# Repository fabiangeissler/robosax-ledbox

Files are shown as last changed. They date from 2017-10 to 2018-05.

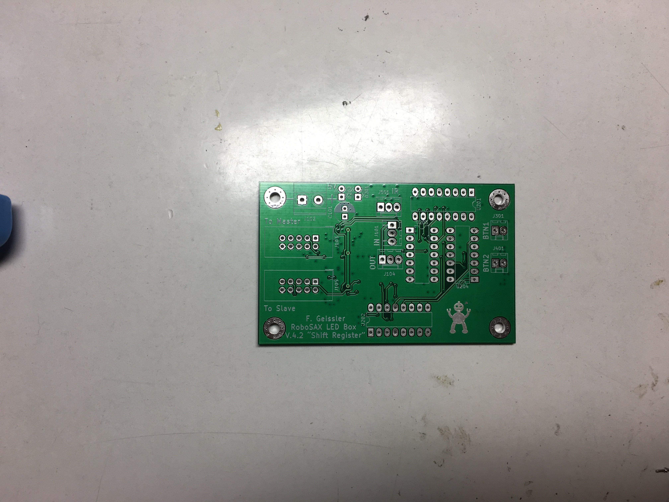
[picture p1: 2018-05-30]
Dokumentation/Fotos/IMG_1938.JPG

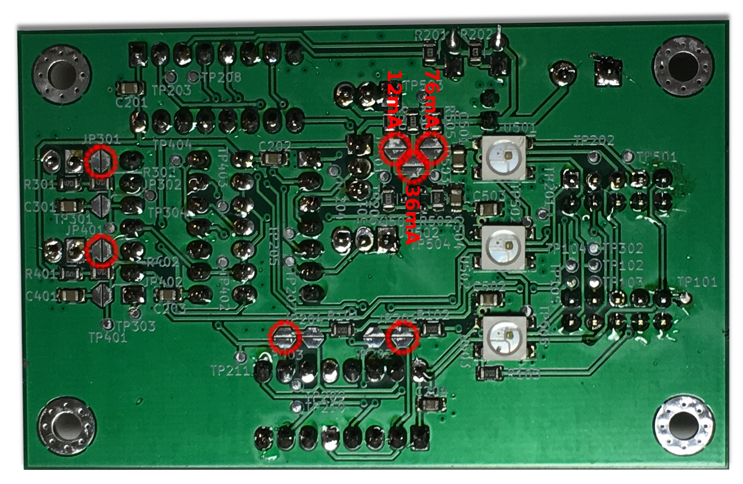
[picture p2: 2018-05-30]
Dokumentation/Fotos/bot_ass.png

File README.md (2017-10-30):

# robosax-ledbox
Bestandteil des Spielfeldes zum RoboSAX Wettbewerb 2018.  

Die Boxen bestehen aus einer RGB LED zur Statusanzeige und einem Button zur Aktivierung durch die Roboter. Zusätzlich enthält jede Box eine infrarot LED in der Nähe des Buttons um Daten an den Roboter zu übermitteln. Die Nutzung der IR LED ist für den Wettbewerbsablauf nicht notwendig, kann aber Vorteile bringen.  

Genauere Informationen zum mechanichen Aufbau, Maße und Datenprotokolle folgen sobald sie festgelegt wurden.

Fabian Geißler  
RoboSAX Team

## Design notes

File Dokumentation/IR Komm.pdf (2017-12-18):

# RoboSAX 2018

## - Bereich Spielfeldbau -

## Information: Infrarotkommunikation der Spielfeldelemente

## UNVOLLSTÄNDIGE ARBEITSFASSUNG

Einführung

Die optisch-mechanischen Spielfeldelemente (Taster mit LED Anzeige) werden erstmals zum RoboSAX 2018 eingesetzt. Die 24 Einheiten pro Spielfeld sind untereinander vernetzt, wodurch einerseits ein Spielmodus über beide Spielfeldhälften, sowie eine automatische Echtzeitauswertung und Zeitmessung möglich wird.
Darüberhinaus besitzt jede Einheit eine infrarot Schnittstelle, über die der Roboter den aktuellen Spielfeldstatus auslesen kann. Die exakten Spezifikationen dieser Schnittstelle werden in diesem Dokument erläutert.

Ablauf

Nachdem der Taster eines Spielfeltelements betätigt wurde wird die Infrarotschnittstelle aktiviert. Diese verwendet das UART Protokoll zum senden der Daten. Der Empfang von Daten bzw. das Senden von Daten an die Elemente ist nicht möglich.
Zunächst wird ein Byte mit dem Wert 0xAA gesendet. Das entspricht einem umschalten des Datensignals bei jedem Bit und kann zum aufsynchronisieren verwendet werden. Danach folgen drei Bytes, also insgesamt 24 bit, welche eine Information über den Status der jeweiligen Station geben. Bits 0 bis 11 entsprechen Spielfeldhälfte A und Bits 12 bis 23 entsprechen Spielfeldhälfte B.
Eine erneute Kommunikation wird erst durch erneutes drücken des Buttons aktiviert.

Mechanische Daten

- folgt -

Opto-Elektrische Eigenschaften

Elektrische Eigenschaften (interner 8MHz Osc. unkallibriert)

Parameter | Symbol | Min | Typ | Max | Einheit
Spitzenwert Wellenlänge | λp | | 940 | | nm
Spektrale Bandbreite | Δλ | | 45 | | nm
Strahlungsintensität | IE | | 35 | | mW/sr
Abstrahlwinkel | θ | | 35 | | °
Parameter | Symbol | Min | Typ | Max | Einheit
Modulationsfrequenz | fmod | 34,6 | 38 | 38,5 | kHz
Baudrate | Rbaud | 365 | 400 | 405 | 1/s

Protokoll

Da bei UART der normale Zustand einem HIGH Pegel auf der Leitung entspricht wird dieser bei der Infrarotkommunikation durch die Abwesenheit des modulierten Signals repräsentiert. Ein LOW Pegel wird entsprechend durch das modulierte Signal angezeigt.
Die Übertragung eines Byte sieht wie folgt aus:

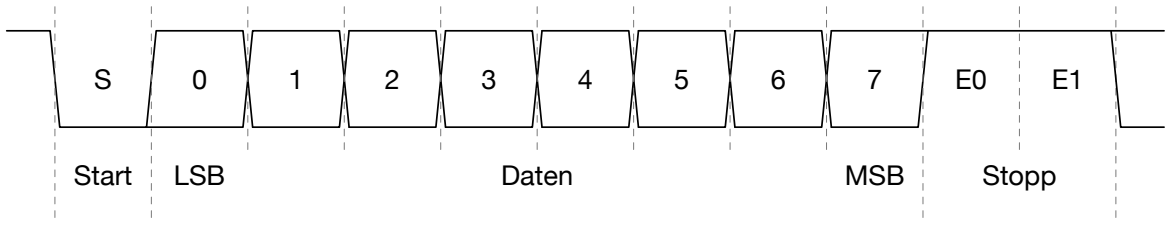
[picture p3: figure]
Start; LSB; Daten; MSB; Stopp

Das modulierte Signal kann mithilfe eines infrarot Demodulationsempfängers, wie zum Beispiel dem TSOP4438 in ein elektrisches TTL UART Signal gewandelt werden. Im Folgenden ist beispielhaft die Übertragung des Bytes 0xAA dargestellt. Der rote Graph stellt dabei das infrarot Signal dar, während der Schwarze den entsprechenden Ausgang des Demodulators zeigt.
Da der Ausgang des Empfängers (hier TSOP4438) bereits das Signal invertiert kann es direkt

auf die UART Peripherie eines Mikrocontrollers gegeben und wie normale UART Daten ausgelesen werden.

Start | MSB | Daten (0xAA) | LSB | Stopp
0 | 1 | 0 | 1 | 0 | 1 | 0 | 1 | 0 | 1 | 1

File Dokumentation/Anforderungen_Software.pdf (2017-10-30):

### Programm allgemein

- Aufgaben:
- System Timer mit Timer1 (16 bit) -> 1us bis 1ms Systemtakt für Buszugriff, Debounce,

Systemzeit und Timings mit geringer Priorität
(muss man testen, wie tief man mit der Zeit gehen kann)
- PWM Steuerung der RGB LED -> Hybrid PWM (Timer 0 Interrupts + Software)
- Button Auswertung und Debouncing, ohne Interrupt.
- INT0 (Button) und INT1 (Bus) nur zum wecken aus IDLE verwenden.
- Buszugriff mit System Timer und UART
- IR LED Datenübertragung Timing mit System Timer
- Adressierung
- Jeder Controller bekommt den seine laufende Nummer (oder einen Hash davon, oder eine

eindeutige Zufallszahl) in den EEPROM geschrieben. Dieser Wert dient zur Adressierung des Controllers auf dem Bus.
- Um der Steuereinheit die Adressen und Positionen bekannt zu machen muss eine Setup

Prozedur entwickelt werden. Z.B. kann von der Steuereinheit ein Setup Modus ausgerufen (Broadcast) werden. In diesem sendet jede LED Box bei Tastendruck ihre eigene Adresse an die Steuereinheit. Um die Positionen zuzuordnen verlangt die Setup Prozedur eine feste Reihenfolge in der die Taster gedrückt werden müssen (z.B. A1 bis A12 und dann B1 bis B12).
- Zufall
- Die Adresse dient zusätzlich als erster seed für den Zufallsgenerator, damit von Anfang an

verschiedene Zufallszahlen garantiert werden können
- Bei jedem Tastendruck wird die aktuelle Systemzeit, evtl. verrechnet mit der Adresse, als neuer seed verwendet.

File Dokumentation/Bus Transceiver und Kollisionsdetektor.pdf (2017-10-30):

### Bus Transceiver

- bisher: SN75176B (Datenblatt) (http://www.ti.com/lit/ds/symlink/sn75176a.pdf)
- veraltet
- hoher Stromverbrauch: 35mA - 50mA
- neu: ST485C (Datenblatt) (http://www.st.com/content/ccc/resource/technical/document/datasheet/4b/81/a8/cd/8a/72/47/82/CD00002183.pdf/files/CD00002183.pdf/jcr:content/translations/en.CD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) oder alternativ ADM485 (Datenblatt) (http://www.analog.com/media/en/technical-documentation/data-sheets/ADM485.pdf)
- 300µA Stromverbrauch (+ Ausgangsströme)
- max. 64 Transceiver pro Bus
- max. 2.5Mbps
- max. Anstiegs/Abfallzeit des Senders: 40ns (relevant für Kollisionsdetektor)
- Bei Kollision am Ausgang: Überlagerung von Fig. 12 und Fig. 13 auf S. 12 im Datenblatt

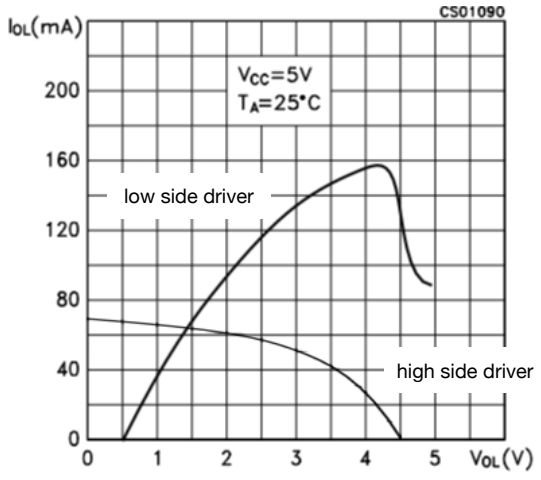
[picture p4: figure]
high side driver; low side driver
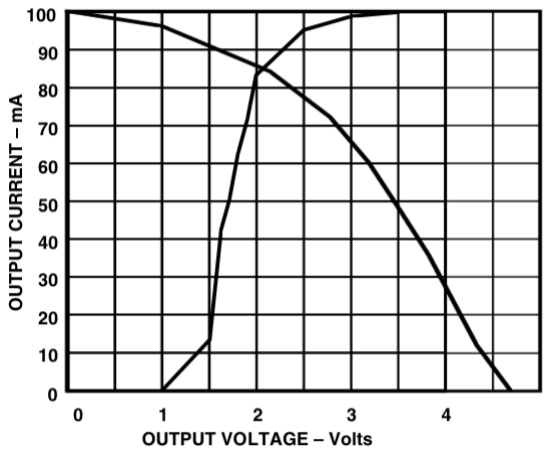
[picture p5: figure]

- es wird sich eine Spannung um 1,5V bei ca. 60mA einstellen
- Bei einer Leitungslänge von 10m mit 216Ω/km (Datenblatt), (http://cdn-reichelt.de/documents/datenblatt/C600/FLACHBANDKABEL.pdf) also 2,16Ω Leitungswiderstand

ergibt sich ein Spannungsabfall im Kabel von rund 130mV. Da dieser Wert über der Hysterese des Empfängers liegt würde der Empfänger auch im Falle einer Kollision genau das empfangen, was der zugehörige Sender sendet. Eine Kollisionserkennung ist so also genau wie beim SN75176B nicht möglich.
- Die Kollisionsdetektorschaltung wird auch hier benötigt, diesmal aber zur Erkennung des

Abfalls des high Pegels.

Sender Ausgangsstrom über Ausgangsspannung ST485C (links) und ADM485 (rechts)

- Kollisionsdetektor

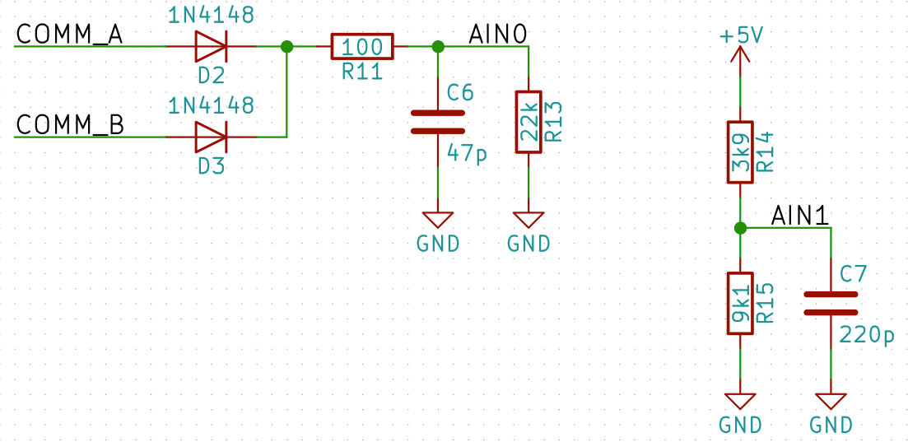
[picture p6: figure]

- Mit den Dioden D2 und D3 wird immer der high Pegel abgegriffen, unabhängig davon, ob er gerade auf A oder B vorherrscht. Der Tiefpass R11 und C6 dient zum Eliminieren der Umschalteinbrüche. R13 erzwingt einen Stromfluss durch die Dioden.
- Bei Betrachtung des letzten Busteilnehmers sieht der Sender standardmäßig als Last die

Leitungsimpedanz und den parallelgeschalteten Abschlusswiderstand. Wenn beide rund 150Ω betragen, ergibt sich eine Last von 75Ω. Im Diagramm unten ergibt das ungefähr den in rot markierten Arbeitspunkt mit einer Differenzspannung von rund 2,7V und 36mA.

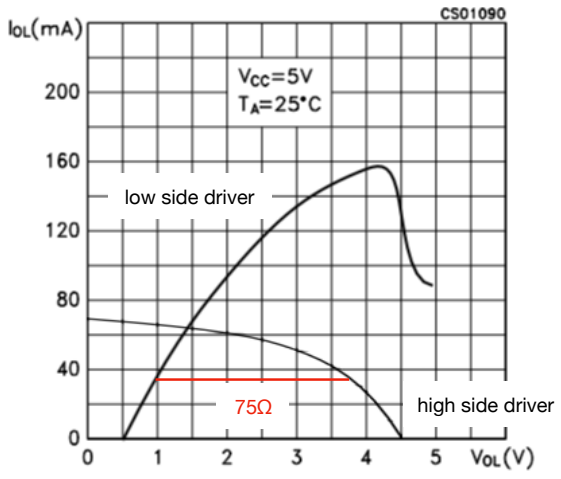
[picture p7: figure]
high side driver; low side driver

- Der Kollisionsdetektor darf also erst bei einem Abfall des high Pegels unter ca. 3,5V oder besser, unter Beachtung von Toleranzen, unter 3V anschlagen.
- Unter Beachtung der Diodenspannung mit 0,5V bis 0,7V darf die Spannung an AIN also nicht unter 2,4V fallen. Da AIN0 und AIN1 im Analog Comparator des Mikrocontrollers verglichen werden muss AIN1 auf diese 2,4V eingestellt werden. Unter Zuhilfenahme des Voltage Divider Calculator von TI (http://www.ti.com/download/kbase/volt/volt_div3.htm) ergeben sich dafür günstige Werte von R14 = 3,3kΩ und R15 = 2,2kΩ.

Sender Ausgangsstrom über Ausgangsspannung

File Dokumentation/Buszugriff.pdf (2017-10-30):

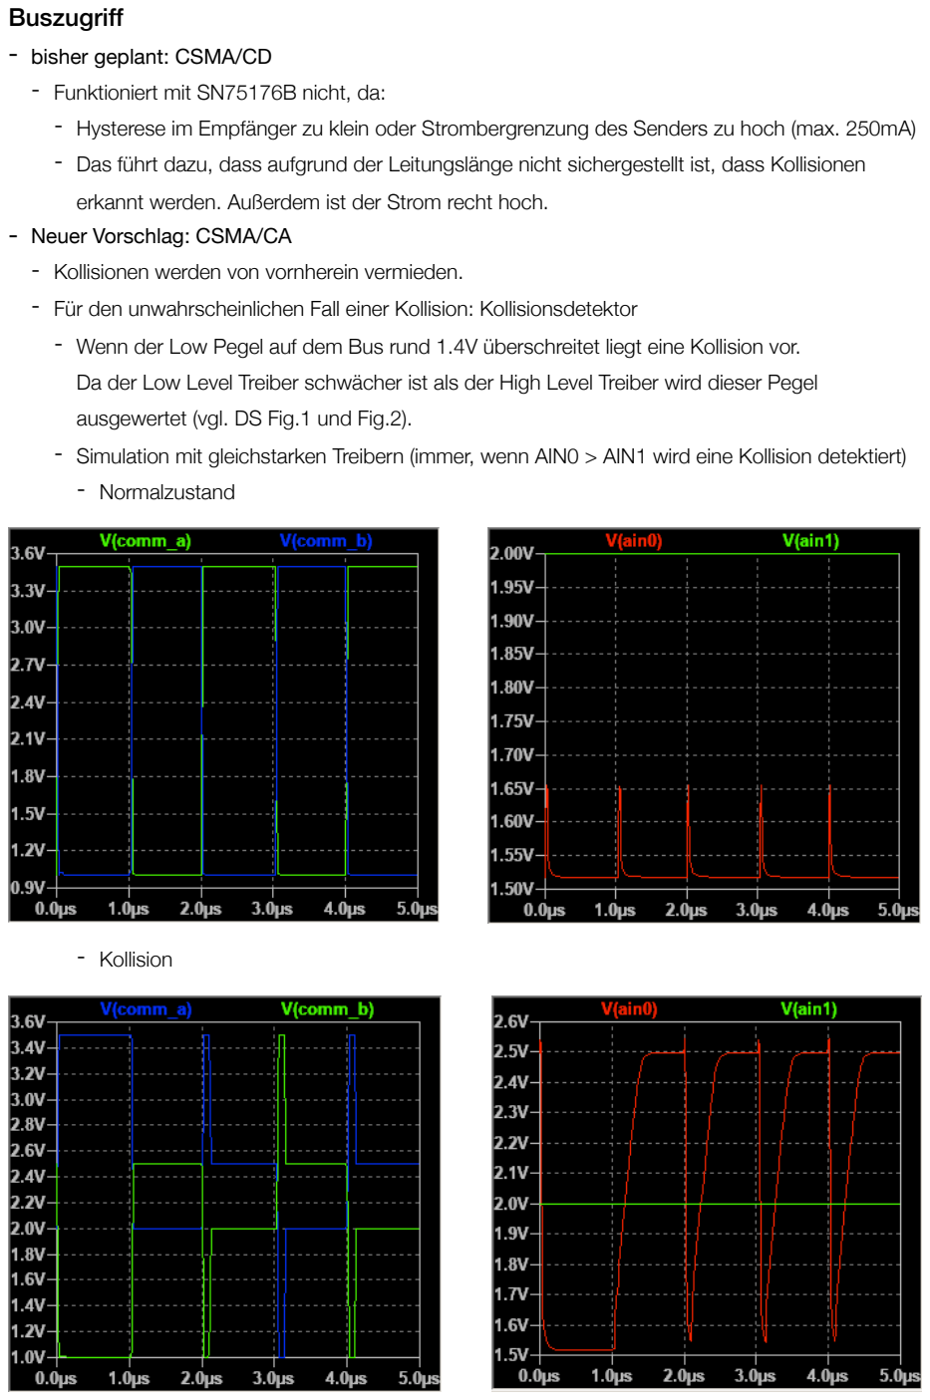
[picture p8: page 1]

### Buszugriff

- bisher geplant: CSMA/CD
- Funktioniert mit SN75176B nicht, da:
- Hysterese im Empfänger zu klein oder Strombergrenzung des Senders zu hoch (max. 250mA)
- Das führt dazu, dass aufgrund der Leitungslänge nicht sichergestellt ist, dass Kollisionen

erkannt werden. Außerdem ist der Strom recht hoch.
- Neuer Vorschlag: CSMA/CA
- Kollisionen werden von vornherein vermieden.
- Für den unwahrscheinlichen Fall einer Kollision: Kollisionsdetektor
- Wenn der Low Pegel auf dem Bus rund 1.4V überschreitet liegt eine Kollision vor.
Da der Low Level Treiber schwächer ist als der High Level Treiber wird dieser Pegel ausgewertet (vgl. DS Fig.1 und Fig.2).
- Simulation mit gleichstarken Treibern (immer, wenn AIN0 > AIN1 wird eine Kollision detektiert)
- Normalzustand
- Kollision

- Ablauf:
1. Teilnehmer wird eingeschaltet
2. Teilnehmer wartet für mindestens die CA (Collision Avoidance) Periode oder die Sendedauer eines Bytes (welche länger ist) und beobachtet den Bus
3. Wenn der Bus frei ist (RX = High Pegel) kann der Teilnehmer senden.
Dazu wird der Bus auf Low Pegel gezogen, es beginnt die CA Periode.
4. Nach einer zufälligen Zeit in der CA Periode wird der Bus freigegeben (Sender auf tristate)
5. Wenn der Bus auf Low bleibt kann nicht gesendet werden, da ein anderer Teilnehmer senden will und zufällig die längere Zeit „gewürfelt“ hat. Weiter mit 8.
6. Wenn der Bus auf High springt kann nach einem kurzen Delay (alle Teilnehmer müssen nach der Low-High Flanke aufwachen) angefangen werden zu senden.
Hierfür wird die UART Peripherie benutzt. Zuerst wird die Adresse des Empfängers gesendet. Danach können alle nicht angesprochenen Teilnehmer wieder schlafen.
7. Sollten zwei Teilnehmer gleichzeitig angefangen haben und auch die gleiche Zeit gezogen haben wird jetzt die Kollisionserkennung anschlagen. In diesem Fall muss von dem Teilnehmer, der sendet und die Kollision erkannt hat, die Kollisionserkennung der anderen Sender provoziert werden. Dafür wird der Bus für die Sendedauer eines Bytes Low gehalten.
8. Wenn der Bus länger als die Sendedauer eines Bytes High bleibt ist er wieder frei. Zurück zu 3.
- warum nicht Daisychain?
- Für Daisychain würde ein weiterer Kommunikationsport am Mikrocontroller und ein weiterer Transceiver benötigt. KO Kriterium ist hier der nicht verfügbare weitere Kommunikationsport.
- Außerdem müsste jedes mal die Nachricht über alle Zwischenstationen gereicht werden. Bei

Fehler einer Station kann ein ganzer Bereich nicht mehr angesprochen werden.

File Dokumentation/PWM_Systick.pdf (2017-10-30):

### Erweiterung der PWM Auflösung

- Problem:
- Der ausgewählte Controller hat nur zwei 16 Bit hardware PWM Kanäle, die restlichen vier

hardware PWM Kanäle haben nur eine Auflösung von 8 Bit.
- Für die RGB LED werden drei Kanäle benötigt.
- Aufgrund der nichtlinearen Helligkeitsempfindlichkeit des Auges wird im kleinen Helligkeitsbereich

eine höhere Auflösung der PWM von mindestens 12 Bit gefordert.
- Lösung 1: Dithering (pwm_dither.h)
- Mithilfe von Dithering kann durch eine vergrößerte Zeitauflösung auch die Auflösung der Helligkeitsstufen vergrößert werden. Dabei hilft die Trägheit des Auges, auf welcher das gesamte Dimmprinzip per PWM basiert.
- Anstatt einer PWM mit z.B. 200Hz wird jetzt eine PWM mit 400Hz genutzt. Dabei wird immer in einer Periode das nächst mögliche geringere Tastverhältnis als der gesetzte Wert verwendet. In der nächsten Periode wird das nächsthöhere Tastverhältnis gesetzt. Im Mittel ergibt sich also genau die Helligkeit wischen beiden Tastverhältnissen. Die PWM Auflösung wurde so um ein Bit erweitert. Die Auflösung kann also mit jeder Frequenzverdopplung um ein Bit erhöht werden.
- Bei 12 Bit wird also eine Frequenz von 200Hz * 2^4 = 3,2kHz benötigt
- Vorteile:
- Benötigte bittiefe kann dynamisch an den eingestellten Tastgrad angepasst werden, wodurch

auch die Frequenz an den jeweiligen Tastgrad angepasst wird und die benötigten CPU Zyklen geringer werden.
- Nachteile:
- Hohe PWM Frequenz stellt hohe Anforderungen an die Flankensteilheit des LED Treibers, sonst wird die Helligkeit insgesamt abgesenkt. Bei geringer Flankensteilheit gibt es zusätzlich Helligkeitssprünge beim Umschalten zwischen verschiedenen Frequenzen.
- Lösung 2: Hybrid zwischen Hardware und Software PWM (pwm_hybrid.h)
- Die vorhandene 8 Bit PWM wird durch einen weiteren 8 Bit Softwarezähler erweitert, welcher

immer beim Überlauf des Hardwarezählers hochgezählt wird. Dadurch verhält er sich exakt wie ein 16 Bit Hardware Kanal, benötigt aber Zusätzliche CPU Zyklen alle 256 Takte.
- Beim Einstellen des Tastverhältnisses wird geprüft, bei welchem Zählerstand des Softwarezählers

der Ausgang von Low auf High springen muss (software compare, SC) und bei welchem Stand des Hardwarezählers dieser Sprung stattfindet (hardware compare, HC).
In jedem Überlauf des Hardwarezählers werden die Werte für die nächste Periode (nicht die direkt folgende) gesetzt. Hier wird nun unterschieden, liegt der Softwarezähler unter SC, wird der Hardware Tastgrad auf 0xFF (Low Pegel) gesetzt. Liegt er über SC wird der Tastgrad auf null (High Pegel) gesetzt. Wenn er gleich SC ist, wird der Hardware Tastgrad auf HC gesetzt. Dadurch wird das Umschalten im korrekten Moment von der Hardware übernommen.

- Vorteile:
- PWM Frequenz wird gering gehalten
- Verhält sich exakt wie ein 16 Bit Hardware Timer
- Nachteile
- Im mittel höhere CPU Last als Dithering, rund 77 Zyklen alle 256 Zyklen (rund 30% Grundlast). Dieser Wert verringert sich allerdings mit der PWM Frequenz bzw. dem Prescaler.
- Lösung 2 ist die Empfohlene

### Systick

- Systick wird vom 16 Bit Timer gesteuert und ist damit abhängig von dessen Auflösung.
- Bei einer Auflösung von 14 Bit bei 16MHz entspricht ein Tick 1,024ms

Die Interruptroutine benötigt 56 Zyklen alle 16385 Takte (0,34% Last)

### Mögliche Änderungen

- In der aktuellen Ausführung haben die PWMs alle eine Auflösung von 14 Bit und einen Prescaler von eins, wodurch sich oben genannter Systick und eine PWM Frequenz von 977Hz (bei 16MHz) ergibt.
- Mit einem Prescaler von acht und mit 12 Bit Auflösung würde die PWM Frequenz auf 488Hz (bei 16MHz) verringert werden. Der Systick würde sich entsprechend verdoppeln. Die CPU Auslastung durch die Hybrid PWM verringert sich allerdings um Faktor acht mit 77 Zyklen alle 2048 Takte (3,8% Grundlast).
- Der Systick könnte zusätzlich im Überlauf des 8 Bit Timers berechnet werden. Dadurch würde ich die Genauigkeit des Systick erheblich verbessern, aber die CPU Auslastung ansteigen. Konkret ergäbe sich bei einem Prescaler von 1 ein Systick alle 16µs und eine Auslastung von zusätzlichen 20 Zyklen pro Überlauf des Timers, also 97 Zyklen alle 256 Takte bzw. 38%.
Mit einem Prescaler von 8 ergäbe sich ein Systick alle 128µs und eine Auslastung von 97 Zyklen alle 2048 Takte bzw. 4,7%.
Für diesen zweiten Fall wäre die Änderung zu empfehlen, damit die Genauigkeit des Systick, gerade für die Kommunikation nicht zu gering wird.

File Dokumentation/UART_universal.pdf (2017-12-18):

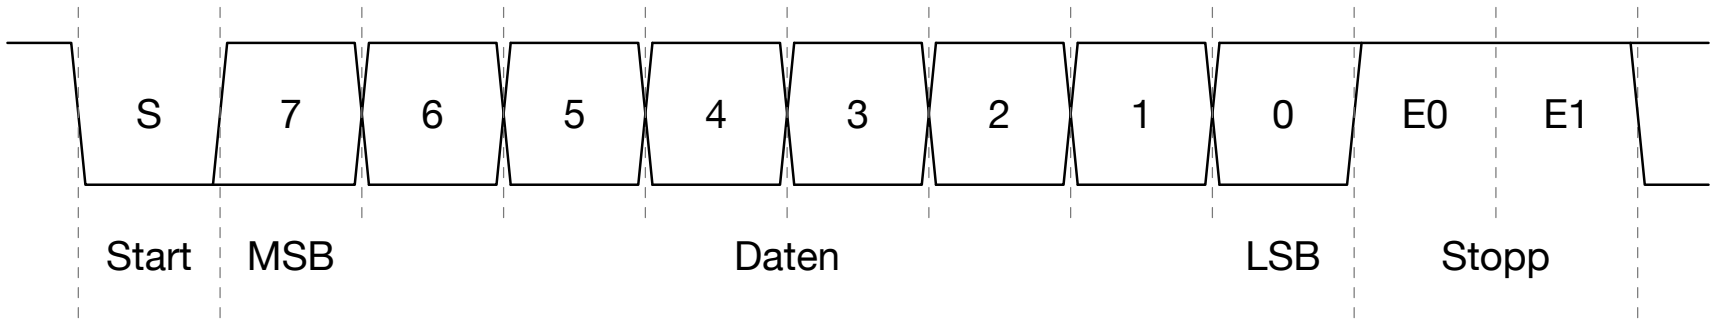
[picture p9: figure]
Start; MSB; Daten; LSB; Stopp

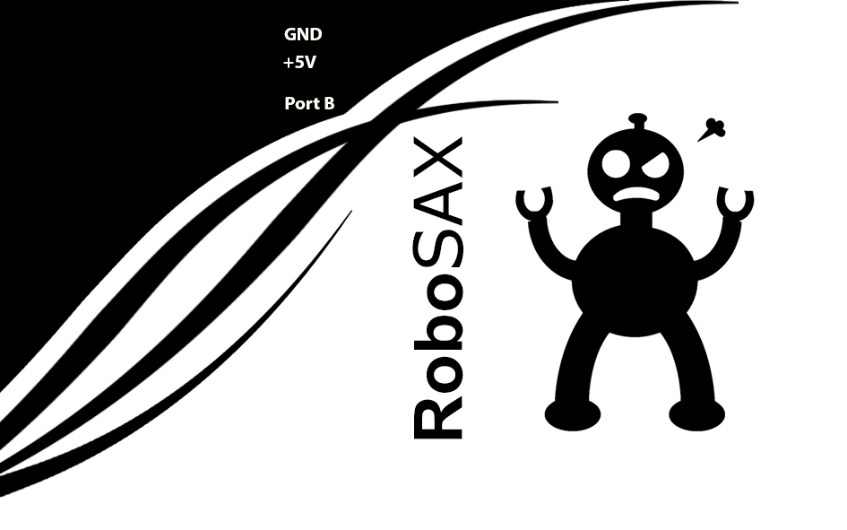
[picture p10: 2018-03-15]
KiCad/SC images/board Kopie.png

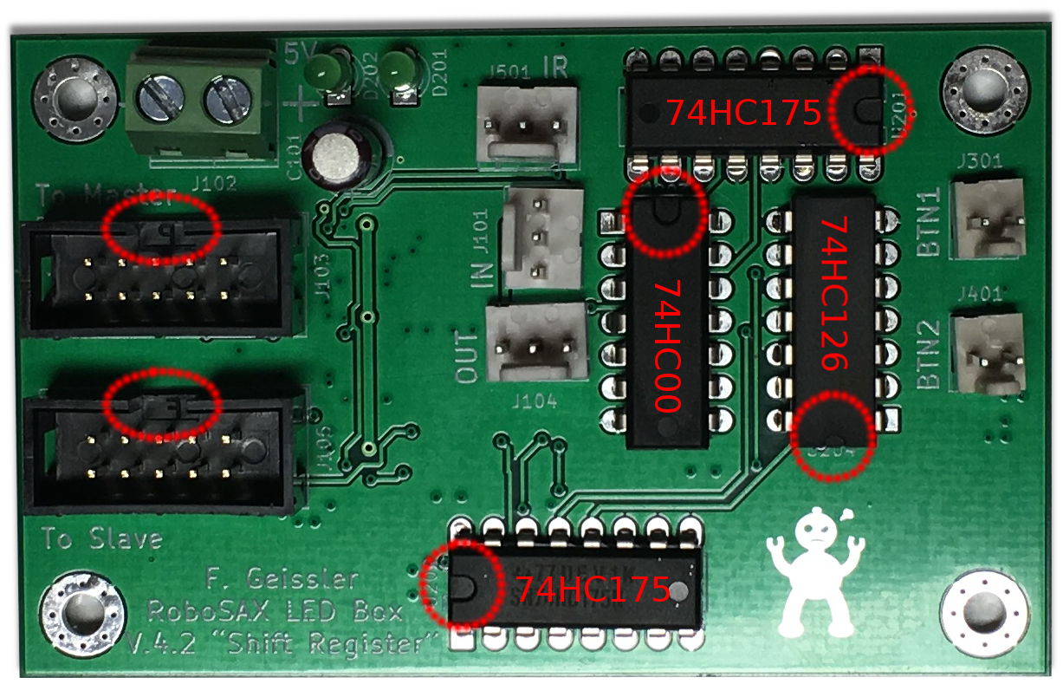
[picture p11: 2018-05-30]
Dokumentation/Fotos/top_ass.png

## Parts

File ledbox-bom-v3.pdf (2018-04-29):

### Table 1

Item | Qty | Reference(s) | Value | LibPart | Footprint | | Alternative | Assembly | Elecrow ID | Elecrow Part | Elecrow Value | Part ID | Digikey | Mouser | Comment
1 | 4 | C201; C501; C502; C503 | 10u | device:C | Capacitors_SMD:C_0805 | 0805 | | | 16532 | C15850 | 10uF (106) ±10% 25V
2 | 3 | C202; C306; C307 | 22p | device:C | Capacitors_SMD:C_0805 | 0805 | | | 2156 | C1804 | 22pF (220) ±5% 50V
3 | 1 | C203 | 470p | device:C | Capacitors_SMD:C_0805 | 0805 | | | 2095 | C1743 | 470pF (471) ±10% 50V
4 | 8 | C301; C302; C303; C304; C305; C402; C403; C504 | 100n | device:C | Capacitors_SMD:C_0805 | 0805 | | | 50686 | C49678 | 100nF(104) ±10% 50V
5 | 1 | C401 | 4u7 25V | device:CP | Capacitors_THT:CP_Radial_D5.0mm_P2.00mm | P2.00mm | | DNP
6 | 1 | C404 | 47u 16V | device:CP | Capacitors_THT:CP_Radial_D6.3mm_P2.50mm | P2.50mm | | | | | | 47µF 16V aluminum electrolytic capacitor | https://www.digikey.de/product-detail/de/panasonic-electronic-components/ECA-1CM470I/P19515CT-ND/6109413 | https://www.mouser.de/ProductDetail/Panasonic/ECA-1CM470I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 | Or similar part
7 | 1 | CON301 | AVR_ISP | atmel:AVR-ISP-6 | Connectors_IDC:IDC-Header_2x03_Pitch2.54mm_Straight | Straight | | | | | | IDC-Header 02x03 Pitch 2.54mm Straight | https://www.digikey.de/product-detail/de/amphenol-fci/75869-331LF/609-5122-ND/1523699 | https://www.mouser.de/ProductDetail/Wurth-Electronics/61200621621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 | Or similar part
8 | 3 | D201; D202; D401 | 1N4148 | device:D | Diodes_SMD:D_SOD-123 | SOD-123 | | | | | | 1N4148W-7-F | https://www.digikey.de/product-detail/de/diodes-incorporated/1N4148W-7-F/1N4148W-FDICT-ND/815280 | https://eu.mouser.com/ProductDetail/Diodes-Incorporated/1N4148W-7-F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
9 | 2 | D402; D502 | LED2 | device:LED | LEDs:LED_D3.0mm | D3.0mm | | DNP
10 | 1 | D403 | PMEG4010ER | device:D_Schottky | Diodes_SMD:D_SOD-123 | SOD-123 | MBR140ESFT3G | | | | | PMEG4010ER,115 | https://www.digikey.de/product-detail/de/nexperia-usa-inc/PMEG4010ER115/1727-5213-1-ND/2531812 | https://www.mouser.de/ProductDetail/Nexperia/PMEG4010ER115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
11 | 1 | D501 | LED1 | device:LED | LEDs:LED_D3.0mm | D3.0mm | | DNP
12 | 1 | J201 | Bus | Connector:Conn_02x05_Odd_Even | Connectors_IDC:IDC-Header_2x05_Pitch2.54mm_Straight | Straight | | | | | | IDC-Header 02x05 Pitch 2.54mm Straight | https://www.digikey.de/product-detail/de/on-shore-technology-inc/302-S101/ED1543-ND/2178422 | https://www.mouser.de/ProductDetail/Wurth-Electronics/61201021621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 | Or similar part
13 | 1 | J301 | Power B | Connector:Conn_02x06_Odd_Even | Socket_Strips:Socket_Strip_Straight_2x06_Pitch2.54mm | Pitch2.54mm | | DNP
14 | 1 | J302 | Port B | Connector:Conn_01x06 | Socket_Strips:Socket_Strip_Straight_1x06_Pitch2.54mm | Pitch2.54mm | | DNP
15 | 1 | J303 | Spare | Connector:Conn_01x02 | Socket_Strips:Socket_Strip_Straight_1x02_Pitch2.54mm | Pitch2.54mm | | DNP
16 | 1 | J304 | UART | Connector:Conn_01x03 | Socket_Strips:Socket_Strip_Straight_1x03_Pitch2.54mm | Pitch2.54mm | | DNP
17 | 1 | J305 | ADC6 | Connector:Conn_01x03 | Socket_Strips:Socket_Strip_Straight_1x03_Pitch2.54mm | Pitch2.54mm | | DNP
18 | 1 | J306 | ADC7 | Connector:Conn_01x03 | Socket_Strips:Socket_Strip_Straight_1x03_Pitch2.54mm | Pitch2.54mm | | DNP
19 | 1 | J401 | 6.5V-12V | Connector:Conn_01x02 | TerminalBlock_MetzConnect:TerminalBlock_MetzConnect_Type055_RT01502HDWU_Pitch5.00mm | Pitch5.00mm | | DNP
20 | 1 | J402 | 5V | Connector:Conn_01x02 | TerminalBlock_MetzConnect:TerminalBlock_MetzConnect_Type055_RT01502HDWU_Pitch5.00mm | Pitch5.00mm | | | | | | Terminal 2 Pin Pitch 5mm | https://www.digikey.de/product-detail/de/amphenol-anytek/VI0201550000G/609-3927-ND/2261273 | https://www.mouser.de/ProductDetail/Bussmann-Eaton/EM367502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 | Or similar part
21 | 1 | J501 | IR LED | Connector:Conn_01x03 | Connectors_Molex:Molex_KK-6410-03_03x2.54mm_Straight | Straight | | | | | | Molex locking header Pitch 2.54mm 3 Pin | https://www.digikey.de/product-detail/de/sullins-connector-solutions/SWR25X-NRTC-S03-ST-BA/S9411-ND/2769653 | https://www.mouser.de/ProductDetail/Molex/22-28-0030?qs=sGAEpiMZZMs%252bGHln7q6pmxD%2f5kNJnZVeZCYy0rFr0qA%3d | Or similar part
22 | 1 | J502 | Button | Connector:Conn_01x02 | Connectors_Molex:Molex_KK-6410-02_02x2.54mm_Straight | Straight | | | | | | Molex locking header Pitch 2.54mm 2 Pin | https://www.digikey.de/product-detail/de/sullins-connector-solutions/SWR25X-NRTC-S02-ST-BA/S9407-ND/2769652 | https://www.mouser.de/ProductDetail/Molex/22-28-0020?qs=sGAEpiMZZMs%252bGHln7q6pm%252bS0pk2Wo0XxW6Wmp6I5P6k%3d | Or similar part
23 | 1 | Q501 | NTR4003N | device:Q_NMOS_GSD | TO_SOT_Packages_SMD:SOT-23 | SMD:SOT-23 | Logic Level N-ch 500mA MOS | | | | | NTR4003NT1G | https://www.digikey.de/product-detail/de/on-semiconductor/NTR4003NT1G/NTR4003NT1GOSCT-ND/1967270 | https://www.mouser.de/ProductDetail/ON-Semiconductor/NTR4003NT1G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
24 | 5 | R201; R506; R507; R508; R509 | 10k | device:R | Resistors_SMD:R_0805 | 0805 | | | 18102 | C17414 | 10KΩ (1002) ±1%
25 | 5 | R202; R204; R301; R302; R303 | 1k | device:R | Resistors_SMD:R_0805 | 0805 | | | 18201 | C17513 | 1KΩ (1001) ±1%
26 | 1 | R203 | 150Ω | device:R | Resistors_SMD:R_0805 | 0805 | | | 18159 | C17471 | 150Ω (1500) ±1%
27 | 3 | R205; R501; R504 | 100Ω | device:R | Resistors_SMD:R_0805 | 0805 | | | 18096 | C17408 | 100Ω (1000) ±1%
28 | 1 | R206 | 22k | device:R | Resistors_SMD:R_0805 | 0805 | | | 18248 | C17560 | 22KΩ (2202) ±1%
29 | 1 | R207 | 3.3k | device:R | Resistors_SMD:R_0805 | 0805 | | | 26753 | C26010 | 3.3KΩ (3301) ±1%
30 | 2 | R208; R401 | 2.2k | device:R | Resistors_SMD:R_0805 | 0805 | | | 18208 | C17520 | 2.2KΩ (2201) ±1%
31 | 1 | R502 | 100k | device:R | Resistors_SMD:R_0805 | 0805 | | | 18095 | C17407 | 100KΩ (1003) ±1%
32 | 1 | R503 | 220Ω | device:R | Resistors_SMD:R_0805 | 0805 | | | 18245 | C17557 | 220Ω (2200) ±1%
33 | 1 | R505 | 47Ω | device:R | Resistors_SMD:R_0805 | 0805 | | | 18402 | C17714 | 47Ω (47R0) ±1%
34 | 2 | R510; R511 | 470Ω | device:R | Resistors_SMD:R_0805 | 0805 | | | 18398 | C17710 | 470Ω (4700) ±1%
35 | 1 | SW501 | Reset | Switch:SW_Push | Buttons_Switches_THT:SW_PUSH_6mm_h5mm | h5mm | | DNP
36 | 1 | SW502 | Push 1 | Switch:SW_Push | Buttons_Switches_THT:SW_PUSH_6mm_h5mm | h5mm | | DNP
37 | 1 | SW503 | Push 2 | Switch:SW_Push | Buttons_Switches_THT:SW_PUSH_6mm_h5mm | h5mm | | DNP
38 | 1 | U201 | ST485C | ledbox-newsymbols:SN75176B | Housings_SOIC:SOIC-8_3.9x4.9mm_Pitch1.27mm | Pitch1.27mm | | | | | | ST485CDR | https://www.digikey.de/product-detail/de/stmicroelectronics/ST485CDR/497-3734-1-ND/686452 | https://www.mouser.de/ProductDetail/STMicroelectronics/ST485CDR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
39 | 1 | U301 | ATMEGA88A-AU | atmel:ATMEGA88A-AU | Housings_QFP:TQFP-32_7x7mm_Pitch0.8mm | Pitch0.8mm | | | | | | ATMEGA88A-AU | https://www.digikey.de/product-detail/de/microchip-technology/ATMEGA88A-AU/ATMEGA88A-AU-ND/2271018 | https://www.mouser.de/ProductDetail/Microchip-Technology-Atmel/ATMEGA88A-AU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
40 | 1 | U401 | AZ1117-5.0 | regul:AZ1117-5.0 | TO_SOT_Packages_SMD:SOT-223-3_TabPin2 | TabPin2 | | DNP
41 | 3 | U501; U502; U503 | WS2812B | worldsemi:WS2812B | LEDs:LED_WS2812B-PLCC4 | WS2812B-PLCC4 | | | | | | WS2812B | - | -
42 | 1 | Y301 | 20MHz | device:Crystal | Crystals:Crystal_HC49-U_Vertical | Vertical | | | | | | CRYSTAL 20.0000MHZ 20PF | https://www.digikey.de/product-detail/de/txc-corporation/9B-20.000MBBK-B/887-2018-ND/3522107 | https://www.mouser.de/ProductDetail/Fox/FOXSLF-200-20?qs=sGAEpiMZZMsBj6bBr9Q9aRTaFt3VVGpld2PX1XJSqd4%3d | Or similar part

### Table 1

Component ID | Component Part Number | Value | Component category | Component type | Footprint | Accuracy | Combined match | Accuracy
1904 | C1552 | 1.5pF (1R5) ±0.25pF 50V | SMD Capacitor | 0402CG1R5C500N T | 0402 | ±0.25pF | 04021.5pF (1R5) ±0.25pF 50V | ±0.25pF | 0.25pF
1911 | C1559 | 2.2pF (2R2) ±0.25pF 50V | SMD Capacitor | 0402CG2R2C500N T | 0402 | ±0.25pF | 04022.2pF (2R2) ±0.25pF 50V | ±0.25pF | 0.25pF
1902 | C1550 | 1pF (1R0) ±0.25pF 50V | SMD Capacitor | 0402CG1R0C500N T | 0402 | ±0.25pF | 04021pF (1R0) ±0.25pF 50V | ±0.25pF | 0.25pF
1991 | C1639 | 1.5pF (1R5) ±0.25pF 50V | SMD Capacitor | 0603CG1R5C500N T | 0603 | ±0.25pF | 06031.5pF (1R5) ±0.25pF 50V | ±0.25pF | 0.25pF
2021 | C1669 | 4.7pF (4R7) ±0.25pF 50V | SMD Capacitor | 0603CG4R7C500N T | 0603 | ±0.25pF | 06034.7pF (4R7) ±0.25pF 50V | ±0.25pF | 0.25pF
2031 | C1679 | 6.8pF (6R8) ±0.25pF 50V | SMD Capacitor | 0603CG6R8C500N T | 0603 | ±0.25pF | 06036.8pF (6R8) ±0.25pF 50V | ±0.25pF | 0.25pF
16831 | C16149 | 2.7pF (2R7) ±0.25pF 50V | SMD Capacitor | CL10C2R7CB8NN NC | 0603 | ±0.25pF | 06032.7pF (2R7) ±0.25pF 50V | ±0.25pF | 0.25pF
22617 | C21895 | 2.0pF (020) ±0.25pF 50V | SMD Capacitor | CL10C020CB8NNN C | 0603 | ±0.25pF | 06032.0pF (020) ±0.25pF 50V | ±0.25pF | 0.25pF
24709 | C23969 | 1.0pF (010) ±0.25pF 50V | SMD Capacitor | CL10C010CB8NNN C | 0603 | ±0.25pF | 06031.0pF (010) ±0.25pF 50V | ±0.25pF | 0.25pF
38453 | C37474 | 6pF (6R0) ±0.25pF 50V | SMD Capacitor | 0603CG6R0C500N T | 0603 | ±0.25pF | 06036pF (6R0) ±0.25pF 50V | ±0.25pF | 0.25pF
47222 | C46219 | 3pF (3R0) ±0.25pF 50V | SMD Capacitor | 0603CG3R0C500N T | 0603 | ±0.25pF | 06033pF (3R0) ±0.25pF 50V | ±0.25pF | 0.25pF
2140 | C1788 | 1.5pF (1R5) ±0.25pF 50V | SMD Capacitor | 0805CG1R5C500N T | 0805 | ±0.25pF | 08051.5pF (1R5) ±0.25pF 50V | ±0.25pF | 0.25pF
2152 | C1800 | 2.0pF (2R0) ±0.25pF 50V | SMD Capacitor | 0805CG2R0C500N T | 0805 | ±0.25pF | 08052.0pF (2R0) ±0.25pF 50V | ±0.25pF | 0.25pF
2155 | C1803 | 2.7pF (2R7) ±0.25pF 50V | SMD Capacitor | 0805CG2R7C500N T | 0805 | ±0.25pF | 08052.7pF (2R7) ±0.25pF 50V | ±0.25pF | 0.25pF
2172 | C1820 | 4.7pF (4R7) ±0.25pF 50V | SMD Capacitor | 0805CG4R7C500N T | 0805 | ±0.25pF | 08054.7pF (4R7) ±0.25pF 50V | ±0.25pF | 0.25pF
68656 | C67560 | 6pF (6R0) ±0.25pF 50V | SMD Capacitor | 0805CG6R0C500N | 0805 | ±0.25pF | 08056pF (6R0) ±0.25pF 50V | ±0.25pF | 0.25pF
2184 | C1832 | 6.8pF (6R8) ±0.25pF 50V | SMD Capacitor | 0805CG6R8C500N T | 0805 | ±0.25pF | 08056.8pF (6R8) ±0.25pF 50V | ±0.25pF | 0.25pF
50686 | C49678 | 100nF(104) ±10% 50V | SMD Capacitor | CC0805KRX7R9BB 104 | 0805 | ±10% | 0805100nF(104) ±10% 50V | 50V | 0V
4516 | C4109 | 2KΩ (2001) ±1% | SMD Resistor | 2KΩ (2001) ±1% | 0402 | ±1% | 04022KΩ (2001) ±1% | ±1% | 1%
26533 | C25790 | 470KΩ (4703) ±1% | SMD Resistor | RTT024703FTH | 0402 | ±1% | 0402470KΩ (4703) ±1% | ±1% | 1%
17853 | C17168 | 0Ω (0R0) ±1% | SMD Resistor | 0402WGF0000TCE | 0402 | ±1% | 04020Ω (0R0) ±1% | ±1% | 1%
25819 | C25076 | 100Ω (1000) ±1% | SMD Resistor | 0402WGF1000TCE | 0402 | ±1% | 0402100Ω (1000) ±1% | ±1% | 1%
25835 | C25092 | 22Ω (22R0) ±1% | SMD Resistor | 0402WGF220JTCE | 0402 | ±1% | 040222Ω (22R0) ±1% | ±1% | 1%
25860 | C25117 | 470Ω (4700) ±1% | SMD Resistor | 0402WGF4700TCE | 0402 | ±1% | 0402470Ω (4700) ±1% | ±1% | 1%
25863 | C25120 | 49.9Ω (49R9) ±1% | SMD Resistor | 0402WGF499JTCE | 0402 | ±1% | 040249.9Ω (49R9) ±1% | ±1% | 1%
26484 | C25741 | 100KΩ (1003) ±1% | SMD Resistor | 0402WGF1003TCE | 0402 | ±1% | 0402100KΩ (1003) ±1% | ±1% | 1%
26487 | C25744 | 10KΩ (1002) ±1% | SMD Resistor | 0402WGF1002TCE | 0402 | ±1% | 040210KΩ (1002) ±1% | ±1% | 1%
12256 | C11702 | 1KΩ (1001) ±1% | SMD Resistor | 0402WGF1001TCE | 0402 | ±1% | 04021KΩ (1001) ±1% | ±1% | 1%
26535 | C25792 | 47KΩ (4702) ±1% | SMD Resistor | 0402WGF4702TCE | 0402 | ±1% | 040247KΩ (4702) ±1% | ±1% | 1%
26539 | C25796 | 56KΩ (5602) ±1% | SMD Resistor | 0402WGF5602TCE | 0402 | ±1% | 040256KΩ (5602) ±1% | ±1% | 1%
26610 | C25867 | 1.5KΩ (1501) ±1% | SMD Resistor | 0402WGF1501TCE | 0402 | ±1% | 04021.5KΩ (1501) ±1% | ±1% | 1%
26622 | C25879 | 2.2KΩ (2201) ±1% | SMD Resistor | 0402WGF2201TCE | 0402 | ±1% | 04022.2KΩ (2201) ±1% | ±1% | 1%
26633 | C25890 | 3.3KΩ (3301) ±1% | SMD Resistor | 0402WGF3301TCE | 0402 | ±1% | 04023.3KΩ (3301) ±1% | ±1% | 1%
26643 | C25900 | 4.7KΩ (4701) ±1% | SMD Resistor | 0402WGF4701TCE | 0402 | ±1% | 04024.7KΩ (4701) ±1% | ±1% | 1%
26826 | C26083 | 1MΩ (1004) ±1% | SMD Resistor | 0402WGF1004TCE | 0402 | ±1% | 04021MΩ (1004) ±1% | ±1% | 1%
4579 | C4172 | 1.5MΩ (1504) ±1% | SMD Resistor | 0603WAF1504T5E | 0603 | ±1% | 06031.5MΩ (1504) ±1% | ±1% | 1%
4591 | C4184 | 20KΩ (2002) ±1% | SMD Resistor | 0603WAF2002T5E | 0603 | ±1% | 060320KΩ (2002) ±1% | ±1% | 1%
4623 | C4216 | 33KΩ (3302) ±1% | SMD Resistor | 0603WAF3302T5E | 0603 | ±1% | 060333KΩ (3302) ±1% | ±1% | 1%
4682 | C4275 | 75Ω (75R0) ±1% | SMD Resistor | 0603WAF750JT5E | 0603 | ±1% | 060375Ω (75R0) ±1% | ±1% | 1%
7726 | C7250 | 10MΩ (1005) ±1% | SMD Resistor | 0603WAF1005T5E | 0603 | ±1% | 060310MΩ (1005) ±1% | ±1% | 1%
8708 | C8218 | 200Ω (2000) ±1% | SMD Resistor | 0603WAF2000T5E | 0603 | ±1% | 0603200Ω (2000) ±1% | ±1% | 1%
13081 | C12447 | 40.2KΩ (4022) ±1% | SMD Resistor | 0603WAF4022T5E | 0603 | ±1% | 060340.2KΩ (4022) ±1% | ±1% | 1%
13967 | C13320 | 5.1MΩ (5104) ±1% | SMD Resistor | 0603F5104T5E | 0603 | ±1% | 06035.1MΩ (5104) ±1% | ±1% | 1%
21904 | C21190 | 1KΩ (1001) ±1% | SMD Resistor | 0603F1001T5E | 0603 | ±1% | 06031KΩ (1001) ±1% | ±1% | 1%
23492 | C22765 | 1.2KΩ (1201) ±1% | SMD Resistor | 0603WAF1201T5E | 0603 | ±1% | 06031.2KΩ (1201) ±1% | ±1% | 1%
23493 | C22766 | 1.2MΩ (1204) ±1% | SMD Resistor | 0603WAF1204T5E | 0603 | ±1% | 06031.2MΩ (1204) ±1% | ±1% | 1%
23502 | C22775 | 100Ω (1000) ±1% | SMD Resistor | 0603WAF1000T5E | 0603 | ±1% | 0603100Ω (1000) ±1% | ±1% | 1%
23514 | C22787 | 120Ω (1200) ±1% | SMD Resistor | 0603WAF1200T5E | 0603 | ±1% | 0603120Ω (1200) ±1% | ±1% | 1%
23517 | C22790 | 12KΩ (1202) ±1% | SMD Resistor | 0603WAF1202T5E | 0603 | ±1% | 060312KΩ (1202) ±1% | ±1% | 1%
23524 | C22797 | 13KΩ (1302) ±1% | SMD Resistor | 0603WAF1302T5E | 0603 | ±1% | 060313KΩ (1302) ±1% | ±1% | 1%
23534 | C22807 | 150KΩ (1503) ±1% | SMD Resistor | 0603WAF1503T5E | 0603 | ±1% | 0603150KΩ (1503) ±1% | ±1% | 1%
23535 | C22808 | 150Ω (1500) ±1% | SMD Resistor | 0603WAF1500T5E | 0603 | ±1% | 0603150Ω (1500) ±1% | ±1% | 1%
23536 | C22809 | 15KΩ (1502) ±1% | SMD Resistor | 0603WAF1502T5E | 0603 | ±1% | 060315KΩ (1502) ±1% | ±1% | 1%
23537 | C22810 | 15Ω (15R0) ±1% | SMD Resistor | 0603WAF150JT5E | 0603 | ±1% | 060315Ω (15R0) ±1% | ±1% | 1%
23545 | C22818 | 16KΩ (1602) ±1% | SMD Resistor | 0603WAF1602T5E | 0603 | ±1% | 060316KΩ (1602) ±1% | ±1% | 1%
23554 | C22827 | 180KΩ (1803) ±1% | SMD Resistor | 0603WAF1803T5E | 0603 | ±1% | 0603180KΩ (1803) ±1% | ±1% | 1%
23555 | C22828 | 180Ω (1800) ±1% | SMD Resistor | 0603WAF1800T5E | 0603 | ±1% | 0603180Ω (1800) ±1% | ±1% | 1%
23570 | C22843 | 1.5KΩ (1501) ±1% | SMD Resistor | 0603WAF1501T5E | 0603 | ±1% | 06031.5KΩ (1501) ±1% | ±1% | 1%
4584 | C4177 | 1.8KΩ (1801) ±1% | SMD Resistor | 0603WAF1801T5E | 0603 | ±1% | 06031.8KΩ (1801) ±1% | ±1% | 1%
23579 | C22852 | 1.8MΩ (1804) ±1% | SMD Resistor | 0603WAF1804T5E | 0603 | ±1% | 06031.8MΩ (1804) ±1% | ±1% | 1%
23586 | C22859 | 10Ω (10R0) ±1% | SMD Resistor | 0603WAF100JT5E | 0603 | ±1% | 060310Ω (10R0) ±1% | ±1% | 1%
23662 | C22935 | 1MΩ (1004) ±1% | SMD Resistor | 0603WAF1004T5E | 0603 | ±1% | 06031MΩ (1004) ±1% | ±1% | 1%
23663 | C22936 | 1Ω (1R00) ±1% | SMD Resistor | 0603WAF100KT5E | 0603 | ±1% | 06031Ω (1R00) ±1% | ±1% | 1%
4597 | C4190 | 2.2KΩ (2201) ±1% | SMD Resistor | 0603WAF2201T5E | 0603 | ±1% | 06032.2KΩ (2201) ±1% | ±1% | 1%
23665 | C22938 | 2.2MΩ (2204) ±1% | SMD Resistor | 0603WAF2204T5E | 0603 | ±1% | 06032.2MΩ (2204) ±1% | ±1% | 1%
23666 | C22939 | 2.2Ω (2R20) ±1% | SMD Resistor | 0603WAF220KT5E | 0603 | ±1% | 06032.2Ω (2R20) ±1% | ±1% | 1%
23667 | C22940 | 2.4KΩ (2401) ±1% | SMD Resistor | 0603WAF2401T5E | 0603 | ±1% | 06032.4KΩ (2401) ±1% | ±1% | 1%
13814 | C13167 | 2.7KΩ (2701) ±1% | SMD Resistor | 0603WAF2701T5E | 0603 | ±1% | 06032.7KΩ (2701) ±1% | ±1% | 1%
23677 | C22950 | 20Ω (20R0) ±1% | SMD Resistor | 0603WAF200JT5E | 0603 | ±1% | 060320Ω (20R0) ±1% | ±1% | 1%
23688 | C22961 | 220KΩ (2203) ±1% | SMD Resistor | 0603WAF2203T5E | 0603 | ±1% | 0603220KΩ (2203) ±1% | ±1% | 1%
23689 | C22962 | 220Ω (2200) ±1% | SMD Resistor | 0603WAF2200T5E | 0603 | ±1% | 0603220Ω (2200) ±1% | ±1% | 1%
23692 | C22965 | 270KΩ (2703) ±1% | SMD Resistor | 0603WAF2703T5E | 0603 | ±1% | 0603270KΩ (2703) ±1% | ±1% | 1%
23693 | C22966 | 270Ω (2700) ±1% | SMD Resistor | 0603WAF2700T5E | 0603 | ±1% | 0603270Ω (2700) ±1% | ±1% | 1%
23694 | C22967 | 27KΩ (2702) ±1% | SMD Resistor | 0603WAF2702T5E | 0603 | ±1% | 060327KΩ (2702) ±1% | ±1% | 1%
23702 | C22975 | 2KΩ (2001) ±1% | SMD Resistor | 0603WAF2001T5E | 0603 | ±1% | 06032KΩ (2001) ±1% | ±1% | 1%
23703 | C22976 | 2MΩ (2004) ±1% | SMD Resistor | 0603WAF2004T5E | 0603 | ±1% | 06032MΩ (2004) ±1% | ±1% | 1%
23704 | C22977 | 2Ω (2R00) ±1% | SMD Resistor | 0603WAF200KT5E | 0603 | ±1% | 06032Ω (2R00) ±1% | ±1% | 1%
23705 | C22978 | 3.3KΩ (3301) ±1% | SMD Resistor | 0603WAF3301T5E | 0603 | ±1% | 06033.3KΩ (3301) ±1% | ±1% | 1%
23707 | C22980 | 3.6KΩ (3601) ±1% | SMD Resistor | 0603WAF3601T5E | 0603 | ±1% | 06033.6KΩ (3601) ±1% | ±1% | 1%
23745 | C23018 | 3.9KΩ (3901) ±1% | SMD Resistor | 0603WAF3901T5E | 0603 | ±1% | 06033.9KΩ (3901) ±1% | ±1% | 1%
23751 | C23024 | 300KΩ (3003) ±1% | SMD Resistor | 0603WAF3003T5E | 0603 | ±1% | 0603300KΩ (3003) ±1% | ±1% | 1%
23752 | C23025 | 300Ω (3000) ±1% | SMD Resistor | 0603WAF3000T5E | 0603 | ±1% | 0603300Ω (3000) ±1% | ±1% | 1%
23773 | C23046 | 4.99KΩ (4991) ±1% | SMD Resistor | 0603WAF4991T5E | 0603 | ±1% | 06034.99KΩ (4991) ±1% | ±1% | 1%
21903 | C21189 | 0Ω (0R0) ±1% | SMD Resistor | 0603WAF0000T5E | 0603 | ±1% | 06030Ω (0R0) ±1% | ±1% | 1%
23864 | C23137 | 330KΩ (3303) ±1% | SMD Resistor | 0603WAF3303T5E | 0603 | ±1% | 0603330KΩ (3303) ±1% | ±1% | 1%
23865 | C23138 | 330Ω (3300) ±1% | SMD Resistor | 0603WAF3300T5E | 0603 | ±1% | 0603330Ω (3300) ±1% | ±1% | 1%
23867 | C23140 | 33Ω (33R0) ±1% | SMD Resistor | 0603WAF330JT5E | 0603 | ±1% | 060333Ω (33R0) ±1% | ±1% | 1%
23874 | C23147 | 36KΩ (3602) ±1% | SMD Resistor | 0603WAF3602T5E | 0603 | ±1% | 060336KΩ (3602) ±1% | ±1% | 1%
23877 | C23150 | 390KΩ (3903) ±1% | SMD Resistor | 0603WAF3903T5E | 0603 | ±1% | 0603390KΩ (3903) ±1% | ±1% | 1%
23878 | C23151 | 390Ω (3900) ±1% | SMD Resistor | 0603WAF3900T5E | 0603 | ±1% | 0603390Ω (3900) ±1% | ±1% | 1%
23880 | C23153 | 39KΩ (3902) ±1% | SMD Resistor | 0603WAF3902T5E | 0603 | ±1% | 060339KΩ (3902) ±1% | ±1% | 1%
4618 | C4211 | 3KΩ (3001) ±1% | SMD Resistor | 0603WAF3001T5E | 0603 | ±1% | 06033KΩ (3001) ±1% | ±1% | 1%
23883 | C23156 | 3MΩ (3004) ±1% | SMD Resistor | 0603WAF3004T5E | 0603 | ±1% | 06033MΩ (3004) ±1% | ±1% | 1%
23886 | C23159 | 4.3KΩ (4301) ±1% | SMD Resistor | 0603WAF4301T5E | 0603 | ±1% | 06034.3KΩ (4301) ±1% | ±1% | 1%
23889 | C23162 | 4.7KΩ (4701) ±1% | SMD Resistor | 0603WAF4701T5E | 0603 | ±1% | 06034.7KΩ (4701) ±1% | ±1% | 1%
23890 | C23163 | 4.7MΩ (4704) ±1% | SMD Resistor | 0603WAF4704T5E | 0603 | ±1% | 06034.7MΩ (4704) ±1% | ±1% | 1%
23891 | C23164 | 4.7Ω (4R70) ±1% | SMD Resistor | 0603WAF470KT5E | 0603 | ±1% | 06034.7Ω (4R70) ±1% | ±1% | 1%
23899 | C23172 | 43KΩ (4302) ±1% | SMD Resistor | 0603WAF4302T5E | 0603 | ±1% | 060343KΩ (4302) ±1% | ±1% | 1%
23905 | C23178 | 470KΩ (4703) ±1% | SMD Resistor | 0603WAF4703T5E | 0603 | ±1% | 0603470KΩ (4703) ±1% | ±1% | 1%
23906 | C23179 | 470Ω (4700) ±1% | SMD Resistor | 0603WAF4700T5E | 0603 | ±1% | 0603470Ω (4700) ±1% | ±1% | 1%
23909 | C23182 | 47Ω (47R0) ±1% | SMD Resistor | 0603WAF470JT5E | 0603 | ±1% | 060347Ω (47R0) ±1% | ±1% | 1%
23911 | C23184 | 49.9KΩ (4992) ±1% | SMD Resistor | 0603WAF4992T5E | 0603 | ±1% | 060349.9KΩ (4992) ±1% | ±1% | 1%
23912 | C23185 | 49.9Ω (49R9) ±1% | SMD Resistor | 0603WAF499JT5E | 0603 | ±1% | 060349.9Ω (49R9) ±1% | ±1% | 1%
23913 | C23186 | 5.1KΩ (5101) ±1% | SMD Resistor | 0603WAF5101T5E | 0603 | ±1% | 06035.1KΩ (5101) ±1% | ±1% | 1%
23916 | C23189 | 5.6KΩ (5601) ±1% | SMD Resistor | 0603WAF5601T5E | 0603 | ±1% | 06035.6KΩ (5601) ±1% | ±1% | 1%
23919 | C23192 | 510KΩ (5103) ±1% | SMD Resistor | 0603WAF5103T5E | 0603 | ±1% | 0603510KΩ (5103) ±1% | ±1% | 1%
23920 | C23193 | 510Ω (5100) ±1% | SMD Resistor | 0603WAF5100T5E | 0603 | ±1% | 0603510Ω (5100) ±1% | ±1% | 1%
23923 | C23196 | 51KΩ (5102) ±1% | SMD Resistor | 0603WAF5102T5E | 0603 | ±1% | 060351KΩ (5102) ±1% | ±1% | 1%
23930 | C23203 | 560KΩ (5603) ±1% | SMD Resistor | 0603WAF5603T5E | 0603 | ±1% | 0603560KΩ (5603) ±1% | ±1% | 1%
23931 | C23204 | 560Ω (5600) ±1% | SMD Resistor | 0603WAF5600T5E | 0603 | ±1% | 0603560Ω (5600) ±1% | ±1% | 1%
23933 | C23206 | 56KΩ (5602) ±1% | SMD Resistor | 0603WAF5602T5E | 0603 | ±1% | 060356KΩ (5602) ±1% | ±1% | 1%
23939 | C23212 | 6.8KΩ (6801) ±1% | SMD Resistor | 0603WAF6801T5E | 0603 | ±1% | 06036.8KΩ (6801) ±1% | ±1% | 1%
23948 | C23221 | 62KΩ (6202) ±1% | SMD Resistor | 0603WAF6202T5E | 0603 | ±1% | 060362KΩ (6202) ±1% | ±1% | 1%
23955 | C23228 | 680Ω (6800) ±1% | SMD Resistor | 0603WAF6800T5E | 0603 | ±1% | 0603680Ω (6800) ±1% | ±1% | 1%
23958 | C23231 | 68KΩ (6802) ±1% | SMD Resistor | 0603WAF6802T5E | 0603 | ±1% | 060368KΩ (6802) ±1% | ±1% | 1%
23961 | C23234 | 7.5KΩ (7501) ±1% | SMD Resistor | 0603WAF7501T5E | 0603 | ±1% | 06037.5KΩ (7501) ±1% | ±1% | 1%
23968 | C23241 | 750Ω (7500) ±1% | SMD Resistor | 0603WAF7500T5E | 0603 | ±1% | 0603750Ω (7500) ±1% | ±1% | 1%
23969 | C23242 | 75KΩ (7502) ±1% | SMD Resistor | 0603WAF7502T5E | 0603 | ±1% | 060375KΩ (7502) ±1% | ±1% | 1%
23980 | C23253 | 820Ω (8200) ±1% | SMD Resistor | 0603WAF8200T5E | 0603 | ±1% | 0603820Ω (8200) ±1% | ±1% | 1%
23981 | C23254 | 82KΩ (8202) ±1% | SMD Resistor | 0603WAF8202T5E | 0603 | ±1% | 060382KΩ (8202) ±1% | ±1% | 1%
23987 | C23260 | 9.1KΩ (9101) ±1% | SMD Resistor | 0603WAF9101T5E | 0603 | ±1% | 06039.1KΩ (9101) ±1% | ±1% | 1%
23992 | C23265 | 91KΩ (9102) ±1% | SMD Resistor | 0603WAF9102T5E | 0603 | ±1% | 060391KΩ (9102) ±1% | ±1% | 1%
24078 | C23345 | 22Ω (22R0) ±1% | SMD Resistor | 0603WAF220JT5E | 0603 | ±1% | 060322Ω (22R0) ±1% | ±1% | 1%
4604 | C4197 | 240KΩ (2403) ±1% | SMD Resistor | 0603WAF2403T5E | 0603 | ±1% | 0603240KΩ (2403) ±1% | ±1% | 1%
24083 | C23350 | 240Ω (2400) ±1% | SMD Resistor | 0603WAF2400T5E | 0603 | ±1% | 0603240Ω (2400) ±1% | ±1% | 1%
24085 | C23352 | 24KΩ (2402) ±1% | SMD Resistor | 0603WAF2402T5E | 0603 | ±1% | 060324KΩ (2402) ±1% | ±1% | 1%
25933 | C25190 | 27Ω (27R0) ±1% | SMD Resistor | 0603WAF270JT5E | 0603 | ±1% | 060327Ω (27R0) ±1% | ±1% | 1%
25939 | C25196 | 56Ω (56R0) ±1% | SMD Resistor | 0603WAF560JT5E | 0603 | ±1% | 060356Ω (56R0) ±1% | ±1% | 1%
25940 | C25197 | 5.1Ω (5R10) ±1% | SMD Resistor | 0603WAF510KT5E | 0603 | ±1% | 06035.1Ω (5R10) ±1% | ±1% | 1%
26546 | C25803 | 100KΩ (1003) ±1% | SMD Resistor | 0603WAF1003T5E | 0603 | ±1% | 0603100KΩ (1003) ±1% | ±1% | 1%
26548 | C25805 | 110KΩ (1103) ±1% | SMD Resistor | 0603WAF1103T5E | 0603 | ±1% | 0603110KΩ (1103) ±1% | ±1% | 1%
26551 | C25808 | 120KΩ (1203) ±1% | SMD Resistor | 0603WAF1203T5E | 0603 | ±1% | 0603120KΩ (1203) ±1% | ±1% | 1%
26553 | C25810 | 18KΩ (1802) ±1% | SMD Resistor | 0603WAF1802T5E | 0603 | ±1% | 060318KΩ (1802) ±1% | ±1% | 1%
26554 | C25811 | 200KΩ (2003) ±1% | SMD Resistor | 0603WAF2003T5E | 0603 | ±1% | 0603200KΩ (2003) ±1% | ±1% | 1%
26562 | C25819 | 47KΩ (4702) ±1% | SMD Resistor | 0603WAF4702T5E | 0603 | ±1% | 060347KΩ (4702) ±1% | ±1% | 1%
26565 | C25822 | 680KΩ (6803) ±1% | SMD Resistor | 0603WAF6803T5E | 0603 | ±1% | 0603680KΩ (6803) ±1% | ±1% | 1%
26693 | C25950 | 11KΩ (1102) ±1% | SMD Resistor | 0603WAF1102T5E | 0603 | ±1% | 060311KΩ (1102) ±1% | ±1% | 1%
26724 | C25981 | 8.2KΩ (8201) ±1% | SMD Resistor | 0603WAF8201T5E | 0603 | ±1% | 06038.2KΩ (8201) ±1% | ±1% | 1%
28341 | C27592 | 68Ω (68R0) ±1% | SMD Resistor | 0603 F680JT5E | 0603 | ±1% | 060368Ω (68R0) ±1% | ±1% | 1%
32812 | C31850 | 22KΩ (2202) ±1% | SMD Resistor | 0603F2202T5E | 0603 | ±1% | 060322KΩ (2202) ±1% | ±1% | 1%
26547 | C25804 | 10KΩ (1002) ±1% | SMD Resistor | 0603WAF1002T5E | 0603 | ±1% | 060310KΩ (1002) ±1% | ±1% | 1%
23924 | C23197 | 51Ω (51R0) ±1% | SMD Resistor | 0603WAF510JT5E | 0603 | ±1% | 060351Ω (51R0) ±1% | ±1% | 1%
23982 | C23255 | 82Ω (82R0) ±1% | SMD Resistor | 0603WAF820JT5E | 0603 | ±1% | 060382Ω (82R0) ±1% | ±1% | 1%
4717 | C4310 | 1.5KΩ (1501) ±1% | SMD Resistor | 0805 F1501T5E | 0805 | ±1% | 08051.5KΩ (1501) ±1% | ±1% | 1%
4767 | C4360 | 36KΩ (3602) ±1% | SMD Resistor | 0805 F3602T5E | 0805 | ±1% | 080536KΩ (3602) ±1% | ±1% | 1%
16467 | C15785 | 560KΩ (5603) ±1% | SMD Resistor | 0805W8F5603T5E | 0805 | ±1% | 0805560KΩ (5603) ±1% | ±1% | 1%
18067 | C17379 | 1.2KΩ (1201) ±1% | SMD Resistor | 0805W8F1201T5E | 0805 | ±1% | 08051.2KΩ (1201) ±1% | ±1% | 1%
18086 | C17398 | 1.8KΩ (1801) ±1% | SMD Resistor | 0805W8F1801T5E | 0805 | ±1% | 08051.8KΩ (1801) ±1% | ±1% | 1%
18095 | C17407 | 100KΩ (1003) ±1% | SMD Resistor | 0805W8F1003T5E | 0805 | ±1% | 0805100KΩ (1003) ±1% | ±1% | 1%
18096 | C17408 | 100Ω (1000) ±1% | SMD Resistor | 0805W8F1000T5E | 0805 | ±1% | 0805100Ω (1000) ±1% | ±1% | 1%
18103 | C17415 | 10Ω (10R0) ±1% | SMD Resistor | 0805W8F100JT5E | 0805 | ±1% | 080510Ω (10R0) ±1% | ±1% | 1%
18117 | C17429 | 11KΩ (1102) ±1% | SMD Resistor | 0805W8F1102T5E | 0805 | ±1% | 080511KΩ (1102) ±1% | ±1% | 1%
18124 | C17436 | 120KΩ (1203) ±1% | SMD Resistor | 0805W8F1203T5E | 0805 | ±1% | 0805120KΩ (1203) ±1% | ±1% | 1%
18125 | C17437 | 120Ω (1200) ±1% | SMD Resistor | 0805W8F1200T5E | 0805 | ±1% | 0805120Ω (1200) ±1% | ±1% | 1%
18132 | C17444 | 12KΩ (1202) ±1% | SMD Resistor | 0805W8F1202T5E | 0805 | ±1% | 080512KΩ (1202) ±1% | ±1% | 1%
18143 | C17455 | 13KΩ (1302) ±1% | SMD Resistor | 0805W8F1302T5E | 0805 | ±1% | 080513KΩ (1302) ±1% | ±1% | 1%
18158 | C17470 | 150KΩ (1503) ±1% | SMD Resistor | 0805W8F1503T5E | 0805 | ±1% | 0805150KΩ (1503) ±1% | ±1% | 1%
18159 | C17471 | 150Ω (1500) ±1% | SMD Resistor | 0805W8F1500T5E | 0805 | ±1% | 0805150Ω (1500) ±1% | ±1% | 1%
18163 | C17475 | 15KΩ (1502) ±1% | SMD Resistor | 0805W8F1502T5E | 0805 | ±1% | 080515KΩ (1502) ±1% | ±1% | 1%
18168 | C17480 | 15Ω (15R0) ±1% | SMD Resistor | 0805W8F150JT5E | 0805 | ±1% | 080515Ω (15R0) ±1% | ±1% | 1%
18189 | C17501 | 180KΩ (1803) ±1% | SMD Resistor | 0805W8F1803T5E | 0805 | ±1% | 0805180KΩ (1803) ±1% | ±1% | 1%
18194 | C17506 | 18KΩ (1802) ±1% | SMD Resistor | 0805W8F1802T5E | 0805 | ±1% | 080518KΩ (1802) ±1% | ±1% | 1%
18201 | C17513 | 1KΩ (1001) ±1% | SMD Resistor | 0805W8F1001T5E | 0805 | ±1% | 08051KΩ (1001) ±1% | ±1% | 1%
18202 | C17514 | 1MΩ (1004) ±1% | SMD Resistor | 0805W8F1004T5E | 0805 | ±1% | 08051MΩ (1004) ±1% | ±1% | 1%
18208 | C17520 | 2.2KΩ (2201) ±1% | SMD Resistor | 0805W8F2201T5E | 0805 | ±1% | 08052.2KΩ (2201) ±1% | ±1% | 1%
18209 | C17521 | 2.2Ω (2R20) ±1% | SMD Resistor | 0805W8F220KT5E | 0805 | ±1% | 08052.2Ω (2R20) ±1% | ±1% | 1%
18214 | C17526 | 2.4KΩ (2401) ±1% | SMD Resistor | 0805W8F2401T5E | 0805 | ±1% | 08052.4KΩ (2401) ±1% | ±1% | 1%
18218 | C17530 | 2.7KΩ (2701) ±1% | SMD Resistor | 0805W8F2701T5E | 0805 | ±1% | 08052.7KΩ (2701) ±1% | ±1% | 1%
18227 | C17539 | 200KΩ (2003) ±1% | SMD Resistor | 0805W8F2003T5E | 0805 | ±1% | 0805200KΩ (2003) ±1% | ±1% | 1%
18228 | C17540 | 200Ω (2000) ±1% | SMD Resistor | 0805W8F2000T5E | 0805 | ±1% | 0805200Ω (2000) ±1% | ±1% | 1%
4735 | C4328 | 20KΩ (2002) ±1% | SMD Resistor | 0805W8F2002T5E | 0805 | ±1% | 080520KΩ (2002) ±1% | ±1% | 1%
18232 | C17544 | 20Ω (20R0) ±1% | SMD Resistor | 0805W8F200JT5E | 0805 | ±1% | 080520Ω (20R0) ±1% | ±1% | 1%
18244 | C17556 | 220KΩ (2203) ±1% | SMD Resistor | 0805W8F2203T5E | 0805 | ±1% | 0805220KΩ (2203) ±1% | ±1% | 1%
18245 | C17557 | 220Ω (2200) ±1% | SMD Resistor | 0805W8F2200T5E | 0805 | ±1% | 0805220Ω (2200) ±1% | ±1% | 1%
18248 | C17560 | 22KΩ (2202) ±1% | SMD Resistor | 0805W8F2202T5E | 0805 | ±1% | 080522KΩ (2202) ±1% | ±1% | 1%
18249 | C17561 | 22Ω (22R0) ±1% | SMD Resistor | 0805W8F220JT5E | 0805 | ±1% | 080522Ω (22R0) ±1% | ±1% | 1%
18263 | C17575 | 24KΩ (2402) ±1% | SMD Resistor | 0805W8F2402T5E | 0805 | ±1% | 080524KΩ (2402) ±1% | ±1% | 1%
18277 | C17589 | 270KΩ (2703) ±1% | SMD Resistor | 0805W8F2703T5E | 0805 | ±1% | 0805270KΩ (2703) ±1% | ±1% | 1%
18281 | C17593 | 27KΩ (2702) ±1% | SMD Resistor | 0805W8F2702T5E | 0805 | ±1% | 080527KΩ (2702) ±1% | ±1% | 1%
18282 | C17594 | 27Ω (27R0) ±1% | SMD Resistor | 0805W8F270JT5E | 0805 | ±1% | 080527Ω (27R0) ±1% | ±1% | 1%
18292 | C17604 | 2KΩ (2001) ±1% | SMD Resistor | 0805W8F2001T5E | 0805 | ±1% | 08052KΩ (2001) ±1% | ±1% | 1%
18294 | C17606 | 2Ω (2R00) ±1% | SMD Resistor | 0805W8F200KT5E | 0805 | ±1% | 08052Ω (2R00) ±1% | ±1% | 1%
18302 | C17614 | 3.9KΩ (3901) ±1% | SMD Resistor | 0805W8F3901T5E | 0805 | ±1% | 08053.9KΩ (3901) ±1% | ±1% | 1%
18304 | C17616 | 300KΩ (3003) ±1% | SMD Resistor | 0805W8F3003T5E | 0805 | ±1% | 0805300KΩ (3003) ±1% | ±1% | 1%
18305 | C17617 | 300Ω (3000) ±1% | SMD Resistor | 0805W8F3000T5E | 0805 | ±1% | 0805300Ω (3000) ±1% | ±1% | 1%
18317 | C17629 | 330KΩ (3303) ±1% | SMD Resistor | 0805W8F3303T5E | 0805 | ±1% | 0805330KΩ (3303) ±1% | ±1% | 1%
18318 | C17630 | 330Ω (3300) ±1% | SMD Resistor | 0805W8F3300T5E | 0805 | ±1% | 0805330Ω (3300) ±1% | ±1% | 1%
18321 | C17633 | 33KΩ (3302) ±1% | SMD Resistor | 0805W8F3302T5E | 0805 | ±1% | 080533KΩ (3302) ±1% | ±1% | 1%
18322 | C17634 | 33Ω (33R0) ±1% | SMD Resistor | 0805W8F330JT5E | 0805 | ±1% | 080533Ω (33R0) ±1% | ±1% | 1%
18343 | C17655 | 390Ω (3900) ±1% | SMD Resistor | 0805W8F3900T5E | 0805 | ±1% | 0805390Ω (3900) ±1% | ±1% | 1%
18344 | C17656 | 390KΩ (3903) ±1% | SMD Resistor | 0805W8F3903T5E | 0805 | ±1% | 0805390KΩ (3903) ±1% | ±1% | 1%
18349 | C17661 | 3KΩ (3001) ±1% | SMD Resistor | 0805W8F3001T5E | 0805 | ±1% | 08053KΩ (3001) ±1% | ±1% | 1%
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

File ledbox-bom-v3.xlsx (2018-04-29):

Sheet: Sheet 1
Table 1
Item | Qty | Reference(s) | Value | LibPart | Footprint |  | Alternative | Assembly | Elecrow ID | Elecrow Part | Elecrow Value | Part ID | Digikey | Mouser | Comment
1 | 4 | C201; C501; C502; C503 | 10u | device:C | Capacitors_SMD:C_0805 | 0805 |  |  | 16532 | C15850 | 10uF (106) ±10% 25V
2 | 3 | C202; C306; C307 | 22p | device:C | Capacitors_SMD:C_0805 | 0805 |  |  | 2156 | C1804 | 22pF (220) ±5% 50V
3 | 1 | C203 | 470p | device:C | Capacitors_SMD:C_0805 | 0805 |  |  | 2095 | C1743 | 470pF (471) ±10% 50V
4 | 8 | C301; C302; C303; C304; C305; C402; C403; C504 | 100n | device:C | Capacitors_SMD:C_0805 | 0805 |  |  | 50686 | C49678 | 100nF(104) ±10% 50V
5 | 1 | C401 | 4u7 25V | device:CP | Capacitors_THT:CP_Radial_D5.0mm_P2.00mm | P2.00mm |  | DNP
6 | 1 | C404 | 47u 16V | device:CP | Capacitors_THT:CP_Radial_D6.3mm_P2.50mm | P2.50mm |  |  |  |  |  | 47µF 16V aluminum electrolytic capacitor | https://www.digikey.de/product-detail/de/panasonic-electronic-components/ECA-1CM470I/P19515CT-ND/6109413 | https://www.mouser.de/ProductDetail/Panasonic/ECA-1CM470I | Or similar part
7 | 1 | CON301 | AVR_ISP | atmel:AVR-ISP-6 | Connectors_IDC:IDC-Header_2x03_Pitch2.54mm_Straight | Straight |  |  |  |  |  | IDC-Header 02x03 Pitch 2.54mm Straight | https://www.digikey.de/product-detail/de/amphenol-fci/75869-331LF/609-5122-ND/1523699 | https://www.mouser.de/ProductDetail/Wurth-Electronics/61200621621 | Or similar part
8 | 3 | D201; D202; D401 | 1N4148 | device:D | Diodes_SMD:D_SOD-123 | SOD-123 |  |  |  |  |  | 1N4148W-7-F | https://www.digikey.de/product-detail/de/diodes-incorporated/1N4148W-7-F/1N4148W-FDICT-ND/815280 | https://eu.mouser.com/ProductDetail/Diodes-Incorporated/1N4148W-7-F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
9 | 2 | D402; D502 | LED2 | device:LED | LEDs:LED_D3.0mm | D3.0mm |  | DNP
10 | 1 | D403 | PMEG4010ER | device:D_Schottky | Diodes_SMD:D_SOD-123 | SOD-123 | MBR140ESFT3G |  |  |  |  | PMEG4010ER,115 | https://www.digikey.de/product-detail/de/nexperia-usa-inc/PMEG4010ER115/1727-5213-1-ND/2531812 | https://www.mouser.de/ProductDetail/Nexperia/PMEG4010ER115
11 | 1 | D501 | LED1 | device:LED | LEDs:LED_D3.0mm | D3.0mm |  | DNP
12 | 1 | J201 | Bus | Connector:Conn_02x05_Odd_Even | Connectors_IDC:IDC-Header_2x05_Pitch2.54mm_Straight | Straight |  |  |  |  |  | IDC-Header 02x05 Pitch 2.54mm Straight | https://www.digikey.de/product-detail/de/on-shore-technology-inc/302-S101/ED1543-ND/2178422 | https://www.mouser.de/ProductDetail/Wurth-Electronics/61201021621 | Or similar part
13 | 1 | J301 | Power B | Connector:Conn_02x06_Odd_Even | Socket_Strips:Socket_Strip_Straight_2x06_Pitch2.54mm | Pitch2.54mm |  | DNP
14 | 1 | J302 | Port B | Connector:Conn_01x06 | Socket_Strips:Socket_Strip_Straight_1x06_Pitch2.54mm | Pitch2.54mm |  | DNP
15 | 1 | J303 | Spare | Connector:Conn_01x02 | Socket_Strips:Socket_Strip_Straight_1x02_Pitch2.54mm | Pitch2.54mm |  | DNP
16 | 1 | J304 | UART | Connector:Conn_01x03 | Socket_Strips:Socket_Strip_Straight_1x03_Pitch2.54mm | Pitch2.54mm |  | DNP
17 | 1 | J305 | ADC6 | Connector:Conn_01x03 | Socket_Strips:Socket_Strip_Straight_1x03_Pitch2.54mm | Pitch2.54mm |  | DNP
18 | 1 | J306 | ADC7 | Connector:Conn_01x03 | Socket_Strips:Socket_Strip_Straight_1x03_Pitch2.54mm | Pitch2.54mm |  | DNP
19 | 1 | J401 | 6.5V-12V | Connector:Conn_01x02 | TerminalBlock_MetzConnect:TerminalBlock_MetzConnect_Type055_RT01502HDWU_Pitch5.00mm | Pitch5.00mm |  | DNP
20 | 1 | J402 | 5V | Connector:Conn_01x02 | TerminalBlock_MetzConnect:TerminalBlock_MetzConnect_Type055_RT01502HDWU_Pitch5.00mm | Pitch5.00mm |  |  |  |  |  | Terminal 2 Pin Pitch 5mm | https://www.digikey.de/product-detail/de/amphenol-anytek/VI0201550000G/609-3927-ND/2261273 | https://www.mouser.de/ProductDetail/Bussmann-Eaton/EM367502 | Or similar part
21 | 1 | J501 | IR LED | Connector:Conn_01x03 | Connectors_Molex:Molex_KK-6410-03_03x2.54mm_Straight | Straight |  |  |  |  |  | Molex locking header Pitch 2.54mm 3 Pin | https://www.digikey.de/product-detail/de/sullins-connector-solutions/SWR25X-NRTC-S03-ST-BA/S9411-ND/2769653 | https://www.mouser.de/ProductDetail/Molex/22-28-0030 | Or similar part
22 | 1 | J502 | Button | Connector:Conn_01x02 | Connectors_Molex:Molex_KK-6410-02_02x2.54mm_Straight | Straight |  |  |  |  |  | Molex locking header Pitch 2.54mm 2 Pin | https://www.digikey.de/product-detail/de/sullins-connector-solutions/SWR25X-NRTC-S02-ST-BA/S9407-ND/2769652 | https://www.mouser.de/ProductDetail/Molex/22-28-0020 | Or similar part
23 | 1 | Q501 | NTR4003N | device:Q_NMOS_GSD | TO_SOT_Packages_SMD:SOT-23 | SMD:SOT-23 | Logic Level N-ch 500mA MOS |  |  |  |  | NTR4003NT1G | https://www.digikey.de/product-detail/de/on-semiconductor/NTR4003NT1G/NTR4003NT1GOSCT-ND/1967270 | https://www.mouser.de/ProductDetail/ON-Semiconductor/NTR4003NT1G
24 | 5 | R201; R506; R507; R508; R509 | 10k | device:R | Resistors_SMD:R_0805 | 0805 |  |  | 18102 | C17414 | 10KΩ (1002) ±1%
25 | 5 | R202; R204; R301; R302; R303 | 1k | device:R | Resistors_SMD:R_0805 | 0805 |  |  | 18201 | C17513 | 1KΩ (1001) ±1%
26 | 1 | R203 | 150Ω | device:R | Resistors_SMD:R_0805 | 0805 |  |  | 18159 | C17471 | 150Ω (1500) ±1%
27 | 3 | R205; R501; R504 | 100Ω | device:R | Resistors_SMD:R_0805 | 0805 |  |  | 18096 | C17408 | 100Ω (1000) ±1%
28 | 1 | R206 | 22k | device:R | Resistors_SMD:R_0805 | 0805 |  |  | 18248 | C17560 | 22KΩ (2202) ±1%
29 | 1 | R207 | 3.3k | device:R | Resistors_SMD:R_0805 | 0805 |  |  | 26753 | C26010 | 3.3KΩ (3301) ±1%
30 | 2 | R208; R401 | 2.2k | device:R | Resistors_SMD:R_0805 | 0805 |  |  | 18208 | C17520 | 2.2KΩ (2201) ±1%
31 | 1 | R502 | 100k | device:R | Resistors_SMD:R_0805 | 0805 |  |  | 18095 | C17407 | 100KΩ (1003) ±1%
32 | 1 | R503 | 220Ω | device:R | Resistors_SMD:R_0805 | 0805 |  |  | 18245 | C17557 | 220Ω (2200) ±1%
33 | 1 | R505 | 47Ω | device:R | Resistors_SMD:R_0805 | 0805 |  |  | 18402 | C17714 | 47Ω (47R0) ±1%
34 | 2 | R510; R511 | 470Ω | device:R | Resistors_SMD:R_0805 | 0805 |  |  | 18398 | C17710 | 470Ω (4700) ±1%
35 | 1 | SW501 | Reset | Switch:SW_Push | Buttons_Switches_THT:SW_PUSH_6mm_h5mm | h5mm |  | DNP
36 | 1 | SW502 | Push 1 | Switch:SW_Push | Buttons_Switches_THT:SW_PUSH_6mm_h5mm | h5mm |  | DNP
37 | 1 | SW503 | Push 2 | Switch:SW_Push | Buttons_Switches_THT:SW_PUSH_6mm_h5mm | h5mm |  | DNP
38 | 1 | U201 | ST485C | ledbox-newsymbols:SN75176B | Housings_SOIC:SOIC-8_3.9x4.9mm_Pitch1.27mm | Pitch1.27mm |  |  |  |  |  | ST485CDR | https://www.digikey.de/product-detail/de/stmicroelectronics/ST485CDR/497-3734-1-ND/686452 | https://www.mouser.de/ProductDetail/STMicroelectronics/ST485CDR
39 | 1 | U301 | ATMEGA88A-AU | atmel:ATMEGA88A-AU | Housings_QFP:TQFP-32_7x7mm_Pitch0.8mm | Pitch0.8mm |  |  |  |  |  | ATMEGA88A-AU | https://www.digikey.de/product-detail/de/microchip-technology/ATMEGA88A-AU/ATMEGA88A-AU-ND/2271018 | https://www.mouser.de/ProductDetail/Microchip-Technology-Atmel/ATMEGA88A-AU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
40 | 1 | U401 | AZ1117-5.0 | regul:AZ1117-5.0 | TO_SOT_Packages_SMD:SOT-223-3_TabPin2 | TabPin2 |  | DNP
41 | 3 | U501; U502; U503 | WS2812B | worldsemi:WS2812B | LEDs:LED_WS2812B-PLCC4 | WS2812B-PLCC4 |  |  |  |  |  | WS2812B | - | -
42 | 1 | Y301 | 20MHz | device:Crystal | Crystals:Crystal_HC49-U_Vertical | Vertical |  |  |  |  |  | CRYSTAL 20.0000MHZ 20PF | https://www.digikey.de/product-detail/de/txc-corporation/9B-20.000MBBK-B/887-2018-ND/3522107 | https://www.mouser.de/ProductDetail/Fox/FOXSLF-200-20?qs=sGAEpiMZZMsBj6bBr9Q9aRTaFt3VVGpld2PX1XJSqd4%3d | Or similar part

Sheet: Elecrow Parts
Table 1
Component ID | Component Part Number | Value | Component category | Component type | Footprint | Accuracy | Combined match | Accuracy
1904 | C1552 | 1.5pF (1R5) ±0.25pF 50V | SMD Capacitor | 0402CG1R5C500NT | 0402 | ±0.25pF | 04021.5pF (1R5) ±0.25pF 50V | ±0.25pF | 0.25pF
1911 | C1559 | 2.2pF (2R2) ±0.25pF 50V | SMD Capacitor | 0402CG2R2C500NT | 0402 | ±0.25pF | 04022.2pF (2R2) ±0.25pF 50V | ±0.25pF | 0.25pF
1902 | C1550 | 1pF (1R0) ±0.25pF 50V | SMD Capacitor | 0402CG1R0C500NT | 0402 | ±0.25pF | 04021pF (1R0) ±0.25pF 50V | ±0.25pF | 0.25pF
1991 | C1639 | 1.5pF (1R5) ±0.25pF 50V | SMD Capacitor | 0603CG1R5C500NT | 0603 | ±0.25pF | 06031.5pF (1R5) ±0.25pF 50V | ±0.25pF | 0.25pF
2021 | C1669 | 4.7pF (4R7) ±0.25pF 50V | SMD Capacitor | 0603CG4R7C500NT | 0603 | ±0.25pF | 06034.7pF (4R7) ±0.25pF 50V | ±0.25pF | 0.25pF
2031 | C1679 | 6.8pF (6R8) ±0.25pF 50V | SMD Capacitor | 0603CG6R8C500NT | 0603 | ±0.25pF | 06036.8pF (6R8) ±0.25pF 50V | ±0.25pF | 0.25pF
16831 | C16149 | 2.7pF (2R7) ±0.25pF 50V | SMD Capacitor | CL10C2R7CB8NNNC | 0603 | ±0.25pF | 06032.7pF (2R7) ±0.25pF 50V | ±0.25pF | 0.25pF
22617 | C21895 | 2.0pF (020) ±0.25pF 50V | SMD Capacitor | CL10C020CB8NNNC | 0603 | ±0.25pF | 06032.0pF (020) ±0.25pF 50V | ±0.25pF | 0.25pF
24709 | C23969 | 1.0pF (010) ±0.25pF 50V | SMD Capacitor | CL10C010CB8NNNC | 0603 | ±0.25pF | 06031.0pF (010) ±0.25pF 50V | ±0.25pF | 0.25pF
38453 | C37474 | 6pF (6R0) ±0.25pF 50V | SMD Capacitor | 0603CG6R0C500NT | 0603 | ±0.25pF | 06036pF (6R0) ±0.25pF 50V | ±0.25pF | 0.25pF
47222 | C46219 | 3pF (3R0) ±0.25pF 50V | SMD Capacitor | 0603CG3R0C500NT | 0603 | ±0.25pF | 06033pF (3R0) ±0.25pF 50V | ±0.25pF | 0.25pF
2140 | C1788 | 1.5pF (1R5) ±0.25pF 50V | SMD Capacitor | 0805CG1R5C500NT | 0805 | ±0.25pF | 08051.5pF (1R5) ±0.25pF 50V | ±0.25pF | 0.25pF
2152 | C1800 | 2.0pF (2R0) ±0.25pF 50V | SMD Capacitor | 0805CG2R0C500NT | 0805 | ±0.25pF | 08052.0pF (2R0) ±0.25pF 50V | ±0.25pF | 0.25pF
2155 | C1803 | 2.7pF (2R7) ±0.25pF 50V | SMD Capacitor | 0805CG2R7C500NT | 0805 | ±0.25pF | 08052.7pF (2R7) ±0.25pF 50V | ±0.25pF | 0.25pF
2172 | C1820 | 4.7pF (4R7) ±0.25pF 50V | SMD Capacitor | 0805CG4R7C500NT | 0805 | ±0.25pF | 08054.7pF (4R7) ±0.25pF 50V | ±0.25pF | 0.25pF
68656 | C67560 | 6pF (6R0) ±0.25pF 50V | SMD Capacitor | 0805CG6R0C500N | 0805 | ±0.25pF | 08056pF (6R0) ±0.25pF 50V | ±0.25pF | 0.25pF
2184 | C1832 | 6.8pF (6R8) ±0.25pF 50V | SMD Capacitor | 0805CG6R8C500NT | 0805 | ±0.25pF | 08056.8pF (6R8) ±0.25pF 50V | ±0.25pF | 0.25pF
50686 | C49678 | 100nF(104) ±10% 50V | SMD Capacitor | CC0805KRX7R9BB104 | 0805 | ±10% | 0805100nF(104) ±10% 50V | 50V | 0V
4516 | C4109 | 2KΩ (2001) ±1% | SMD Resistor | 2KΩ (2001) ±1% | 0402 | ±1% | 04022KΩ (2001) ±1% | ±1% | 1%
26533 | C25790 | 470KΩ (4703) ±1% | SMD Resistor | RTT024703FTH | 0402 | ±1% | 0402470KΩ (4703) ±1% | ±1% | 1%
17853 | C17168 | 0Ω (0R0) ±1% | SMD Resistor | 0402WGF0000TCE | 0402 | ±1% | 04020Ω (0R0) ±1% | ±1% | 1%
25819 | C25076 | 100Ω (1000) ±1% | SMD Resistor | 0402WGF1000TCE | 0402 | ±1% | 0402100Ω (1000) ±1% | ±1% | 1%
25835 | C25092 | 22Ω (22R0) ±1% | SMD Resistor | 0402WGF220JTCE | 0402 | ±1% | 040222Ω (22R0) ±1% | ±1% | 1%
25860 | C25117 | 470Ω (4700) ±1% | SMD Resistor | 0402WGF4700TCE | 0402 | ±1% | 0402470Ω (4700) ±1% | ±1% | 1%
25863 | C25120 | 49.9Ω (49R9) ±1% | SMD Resistor | 0402WGF499JTCE | 0402 | ±1% | 040249.9Ω (49R9) ±1% | ±1% | 1%
26484 | C25741 | 100KΩ (1003) ±1% | SMD Resistor | 0402WGF1003TCE | 0402 | ±1% | 0402100KΩ (1003) ±1% | ±1% | 1%
26487 | C25744 | 10KΩ (1002) ±1% | SMD Resistor | 0402WGF1002TCE | 0402 | ±1% | 040210KΩ (1002) ±1% | ±1% | 1%
12256 | C11702 | 1KΩ (1001) ±1% | SMD Resistor | 0402WGF1001TCE | 0402 | ±1% | 04021KΩ (1001) ±1% | ±1% | 1%
26535 | C25792 | 47KΩ (4702) ±1% | SMD Resistor | 0402WGF4702TCE | 0402 | ±1% | 040247KΩ (4702) ±1% | ±1% | 1%
26539 | C25796 | 56KΩ (5602) ±1% | SMD Resistor | 0402WGF5602TCE | 0402 | ±1% | 040256KΩ (5602) ±1% | ±1% | 1%
26610 | C25867 | 1.5KΩ (1501) ±1% | SMD Resistor | 0402WGF1501TCE | 0402 | ±1% | 04021.5KΩ (1501) ±1% | ±1% | 1%
26622 | C25879 | 2.2KΩ (2201) ±1% | SMD Resistor | 0402WGF2201TCE | 0402 | ±1% | 04022.2KΩ (2201) ±1% | ±1% | 1%
26633 | C25890 | 3.3KΩ (3301) ±1% | SMD Resistor | 0402WGF3301TCE | 0402 | ±1% | 04023.3KΩ (3301) ±1% | ±1% | 1%
26643 | C25900 | 4.7KΩ (4701) ±1% | SMD Resistor | 0402WGF4701TCE | 0402 | ±1% | 04024.7KΩ (4701) ±1% | ±1% | 1%
26826 | C26083 | 1MΩ (1004) ±1% | SMD Resistor | 0402WGF1004TCE | 0402 | ±1% | 04021MΩ (1004) ±1% | ±1% | 1%
4579 | C4172 | 1.5MΩ (1504) ±1% | SMD Resistor | 0603WAF1504T5E | 0603 | ±1% | 06031.5MΩ (1504) ±1% | ±1% | 1%
4591 | C4184 | 20KΩ (2002) ±1% | SMD Resistor | 0603WAF2002T5E | 0603 | ±1% | 060320KΩ (2002) ±1% | ±1% | 1%
4623 | C4216 | 33KΩ (3302) ±1% | SMD Resistor | 0603WAF3302T5E | 0603 | ±1% | 060333KΩ (3302) ±1% | ±1% | 1%
4682 | C4275 | 75Ω (75R0) ±1% | SMD Resistor | 0603WAF750JT5E | 0603 | ±1% | 060375Ω (75R0) ±1% | ±1% | 1%
7726 | C7250 | 10MΩ (1005) ±1% | SMD Resistor | 0603WAF1005T5E | 0603 | ±1% | 060310MΩ (1005) ±1% | ±1% | 1%
8708 | C8218 | 200Ω (2000) ±1% | SMD Resistor | 0603WAF2000T5E | 0603 | ±1% | 0603200Ω (2000) ±1% | ±1% | 1%
13081 | C12447 | 40.2KΩ (4022) ±1% | SMD Resistor | 0603WAF4022T5E | 0603 | ±1% | 060340.2KΩ (4022) ±1% | ±1% | 1%
13967 | C13320 | 5.1MΩ (5104) ±1% | SMD Resistor | 0603F5104T5E | 0603 | ±1% | 06035.1MΩ (5104) ±1% | ±1% | 1%
21904 | C21190 | 1KΩ (1001) ±1% | SMD Resistor | 0603F1001T5E | 0603 | ±1% | 06031KΩ (1001) ±1% | ±1% | 1%
23492 | C22765 | 1.2KΩ (1201) ±1% | SMD Resistor | 0603WAF1201T5E | 0603 | ±1% | 06031.2KΩ (1201) ±1% | ±1% | 1%
23493 | C22766 | 1.2MΩ (1204) ±1% | SMD Resistor | 0603WAF1204T5E | 0603 | ±1% | 06031.2MΩ (1204) ±1% | ±1% | 1%
23502 | C22775 | 100Ω (1000) ±1% | SMD Resistor | 0603WAF1000T5E | 0603 | ±1% | 0603100Ω (1000) ±1% | ±1% | 1%
23514 | C22787 | 120Ω (1200) ±1% | SMD Resistor | 0603WAF1200T5E | 0603 | ±1% | 0603120Ω (1200) ±1% | ±1% | 1%
23517 | C22790 | 12KΩ (1202) ±1% | SMD Resistor | 0603WAF1202T5E | 0603 | ±1% | 060312KΩ (1202) ±1% | ±1% | 1%
23524 | C22797 | 13KΩ (1302) ±1% | SMD Resistor | 0603WAF1302T5E | 0603 | ±1% | 060313KΩ (1302) ±1% | ±1% | 1%
23534 | C22807 | 150KΩ (1503) ±1% | SMD Resistor | 0603WAF1503T5E | 0603 | ±1% | 0603150KΩ (1503) ±1% | ±1% | 1%
23535 | C22808 | 150Ω (1500) ±1% | SMD Resistor | 0603WAF1500T5E | 0603 | ±1% | 0603150Ω (1500) ±1% | ±1% | 1%
23536 | C22809 | 15KΩ (1502) ±1% | SMD Resistor | 0603WAF1502T5E | 0603 | ±1% | 060315KΩ (1502) ±1% | ±1% | 1%
23537 | C22810 | 15Ω (15R0) ±1% | SMD Resistor | 0603WAF150JT5E | 0603 | ±1% | 060315Ω (15R0) ±1% | ±1% | 1%
23545 | C22818 | 16KΩ (1602) ±1% | SMD Resistor | 0603WAF1602T5E | 0603 | ±1% | 060316KΩ (1602) ±1% | ±1% | 1%
23554 | C22827 | 180KΩ (1803) ±1% | SMD Resistor | 0603WAF1803T5E | 0603 | ±1% | 0603180KΩ (1803) ±1% | ±1% | 1%
23555 | C22828 | 180Ω (1800) ±1% | SMD Resistor | 0603WAF1800T5E | 0603 | ±1% | 0603180Ω (1800) ±1% | ±1% | 1%
23570 | C22843 | 1.5KΩ (1501) ±1% | SMD Resistor | 0603WAF1501T5E | 0603 | ±1% | 06031.5KΩ (1501) ±1% | ±1% | 1%
4584 | C4177 | 1.8KΩ (1801) ±1% | SMD Resistor | 0603WAF1801T5E | 0603 | ±1% | 06031.8KΩ (1801) ±1% | ±1% | 1%
23579 | C22852 | 1.8MΩ (1804) ±1% | SMD Resistor | 0603WAF1804T5E | 0603 | ±1% | 06031.8MΩ (1804) ±1% | ±1% | 1%
23586 | C22859 | 10Ω (10R0) ±1% | SMD Resistor | 0603WAF100JT5E | 0603 | ±1% | 060310Ω (10R0) ±1% | ±1% | 1%
23662 | C22935 | 1MΩ (1004) ±1% | SMD Resistor | 0603WAF1004T5E | 0603 | ±1% | 06031MΩ (1004) ±1% | ±1% | 1%
23663 | C22936 | 1Ω (1R00) ±1% | SMD Resistor | 0603WAF100KT5E | 0603 | ±1% | 06031Ω (1R00) ±1% | ±1% | 1%
4597 | C4190 | 2.2KΩ (2201) ±1% | SMD Resistor | 0603WAF2201T5E | 0603 | ±1% | 06032.2KΩ (2201) ±1% | ±1% | 1%
23665 | C22938 | 2.2MΩ (2204) ±1% | SMD Resistor | 0603WAF2204T5E | 0603 | ±1% | 06032.2MΩ (2204) ±1% | ±1% | 1%
23666 | C22939 | 2.2Ω (2R20) ±1% | SMD Resistor | 0603WAF220KT5E | 0603 | ±1% | 06032.2Ω (2R20) ±1% | ±1% | 1%
23667 | C22940 | 2.4KΩ (2401) ±1% | SMD Resistor | 0603WAF2401T5E | 0603 | ±1% | 06032.4KΩ (2401) ±1% | ±1% | 1%
13814 | C13167 | 2.7KΩ (2701) ±1% | SMD Resistor | 0603WAF2701T5E | 0603 | ±1% | 06032.7KΩ (2701) ±1% | ±1% | 1%
23677 | C22950 | 20Ω (20R0) ±1% | SMD Resistor | 0603WAF200JT5E | 0603 | ±1% | 060320Ω (20R0) ±1% | ±1% | 1%
23688 | C22961 | 220KΩ (2203) ±1% | SMD Resistor | 0603WAF2203T5E | 0603 | ±1% | 0603220KΩ (2203) ±1% | ±1% | 1%
23689 | C22962 | 220Ω (2200) ±1% | SMD Resistor | 0603WAF2200T5E | 0603 | ±1% | 0603220Ω (2200) ±1% | ±1% | 1%
23692 | C22965 | 270KΩ (2703) ±1% | SMD Resistor | 0603WAF2703T5E | 0603 | ±1% | 0603270KΩ (2703) ±1% | ±1% | 1%
23693 | C22966 | 270Ω (2700) ±1% | SMD Resistor | 0603WAF2700T5E | 0603 | ±1% | 0603270Ω (2700) ±1% | ±1% | 1%
23694 | C22967 | 27KΩ (2702) ±1% | SMD Resistor | 0603WAF2702T5E | 0603 | ±1% | 060327KΩ (2702) ±1% | ±1% | 1%
23702 | C22975 | 2KΩ (2001) ±1% | SMD Resistor | 0603WAF2001T5E | 0603 | ±1% | 06032KΩ (2001) ±1% | ±1% | 1%
23703 | C22976 | 2MΩ (2004) ±1% | SMD Resistor | 0603WAF2004T5E | 0603 | ±1% | 06032MΩ (2004) ±1% | ±1% | 1%
23704 | C22977 | 2Ω (2R00) ±1% | SMD Resistor | 0603WAF200KT5E | 0603 | ±1% | 06032Ω (2R00) ±1% | ±1% | 1%
23705 | C22978 | 3.3KΩ (3301) ±1% | SMD Resistor | 0603WAF3301T5E | 0603 | ±1% | 06033.3KΩ (3301) ±1% | ±1% | 1%
23707 | C22980 | 3.6KΩ (3601) ±1% | SMD Resistor | 0603WAF3601T5E | 0603 | ±1% | 06033.6KΩ (3601) ±1% | ±1% | 1%
23745 | C23018 | 3.9KΩ (3901) ±1% | SMD Resistor | 0603WAF3901T5E | 0603 | ±1% | 06033.9KΩ (3901) ±1% | ±1% | 1%
23751 | C23024 | 300KΩ (3003) ±1% | SMD Resistor | 0603WAF3003T5E | 0603 | ±1% | 0603300KΩ (3003) ±1% | ±1% | 1%
23752 | C23025 | 300Ω (3000) ±1% | SMD Resistor | 0603WAF3000T5E | 0603 | ±1% | 0603300Ω (3000) ±1% | ±1% | 1%
23773 | C23046 | 4.99KΩ (4991) ±1% | SMD Resistor | 0603WAF4991T5E | 0603 | ±1% | 06034.99KΩ (4991) ±1% | ±1% | 1%
21903 | C21189 | 0Ω (0R0) ±1% | SMD Resistor | 0603WAF0000T5E | 0603 | ±1% | 06030Ω (0R0) ±1% | ±1% | 1%
23864 | C23137 | 330KΩ (3303) ±1% | SMD Resistor | 0603WAF3303T5E | 0603 | ±1% | 0603330KΩ (3303) ±1% | ±1% | 1%
23865 | C23138 | 330Ω (3300) ±1% | SMD Resistor | 0603WAF3300T5E | 0603 | ±1% | 0603330Ω (3300) ±1% | ±1% | 1%
23867 | C23140 | 33Ω (33R0) ±1% | SMD Resistor | 0603WAF330JT5E | 0603 | ±1% | 060333Ω (33R0) ±1% | ±1% | 1%
23874 | C23147 | 36KΩ (3602) ±1% | SMD Resistor | 0603WAF3602T5E | 0603 | ±1% | 060336KΩ (3602) ±1% | ±1% | 1%
23877 | C23150 | 390KΩ (3903) ±1% | SMD Resistor | 0603WAF3903T5E | 0603 | ±1% | 0603390KΩ (3903) ±1% | ±1% | 1%
23878 | C23151 | 390Ω (3900) ±1% | SMD Resistor | 0603WAF3900T5E | 0603 | ±1% | 0603390Ω (3900) ±1% | ±1% | 1%
23880 | C23153 | 39KΩ (3902) ±1% | SMD Resistor | 0603WAF3902T5E | 0603 | ±1% | 060339KΩ (3902) ±1% | ±1% | 1%
4618 | C4211 | 3KΩ (3001) ±1% | SMD Resistor | 0603WAF3001T5E | 0603 | ±1% | 06033KΩ (3001) ±1% | ±1% | 1%
23883 | C23156 | 3MΩ (3004) ±1% | SMD Resistor | 0603WAF3004T5E | 0603 | ±1% | 06033MΩ (3004) ±1% | ±1% | 1%
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

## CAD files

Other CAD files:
KiCad/gerber_final/ledbox-B.Paste.dxf

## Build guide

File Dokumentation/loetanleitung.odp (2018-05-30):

## LED BOX Oberseite


+ (A)

- (K)

+

## LED BOX Unterseite


Markierte Jumper überbrücken!

Jumper für Stromeinstellung (oben rechts) für ___mA überbrücken!

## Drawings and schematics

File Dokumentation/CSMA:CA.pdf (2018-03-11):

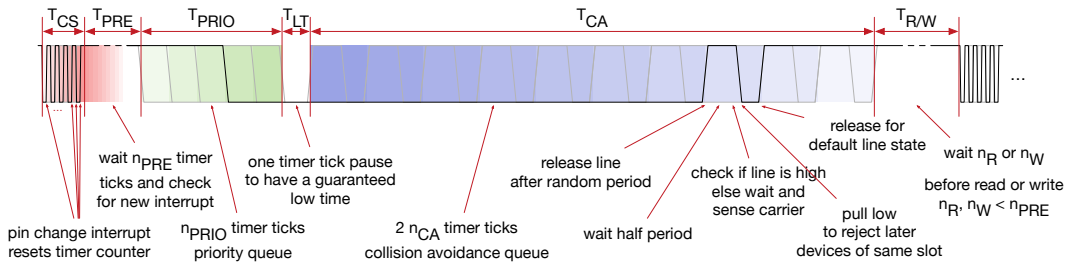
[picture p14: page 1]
release line; after random period; check if line is high; sense carrier; pull low; TPRIO; TCA TCS TPRE; T TLT

release for
default line state

wait nR or nW
before read or write
nR, nW < nPRE

wait nPRE timer
ticks and check
for new interrupt

one timer tick pause
to have a guaranteed
low time

else wait and

pin change interrupt
resets timer counter

nPRIO timer ticks
priority queue

2 nCA timer ticks
collision avoidance queue

wait half period

to reject later
devices of same slot

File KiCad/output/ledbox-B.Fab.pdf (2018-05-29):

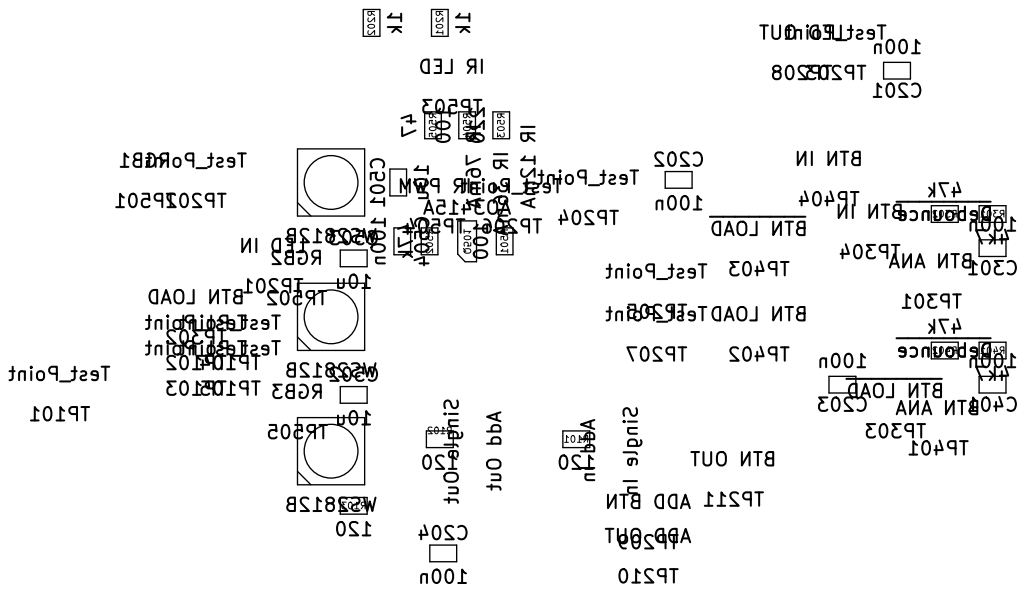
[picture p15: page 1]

LED IN Q501 TP201Test_Point TP202 Test_Point TP203 Test_Point TP204 Test_Point TP205 Test_Point TP206 Test_Point TP207 LED OUT

10u C503 100n C504 Single Out Add Out Single In Add In Debounce Debounce IR 12mA IR 36mA IR 76mA

BTN LOAD TP301 TP302 BTN LOAD

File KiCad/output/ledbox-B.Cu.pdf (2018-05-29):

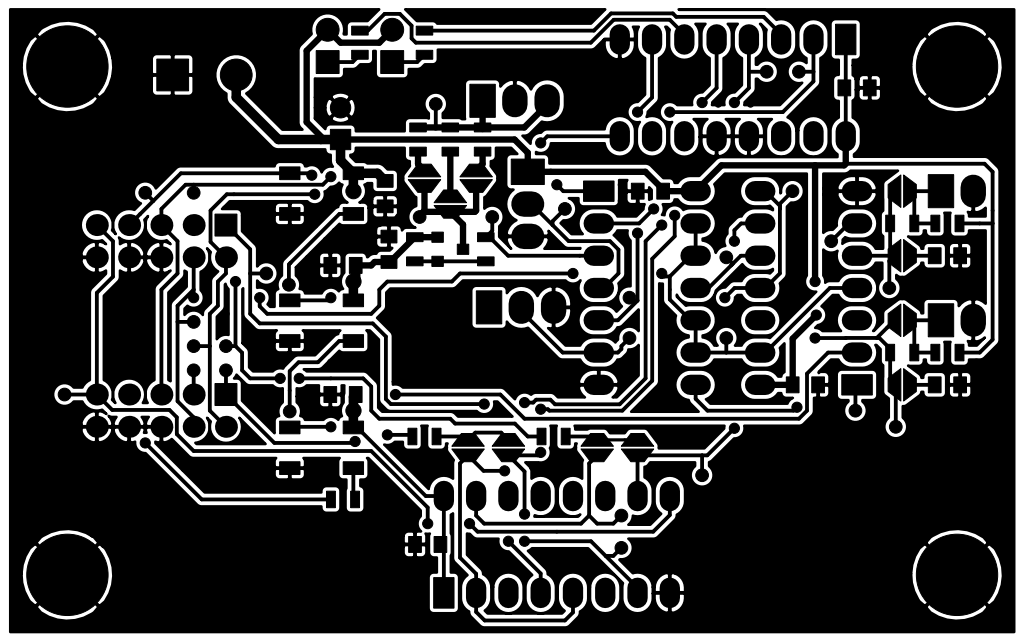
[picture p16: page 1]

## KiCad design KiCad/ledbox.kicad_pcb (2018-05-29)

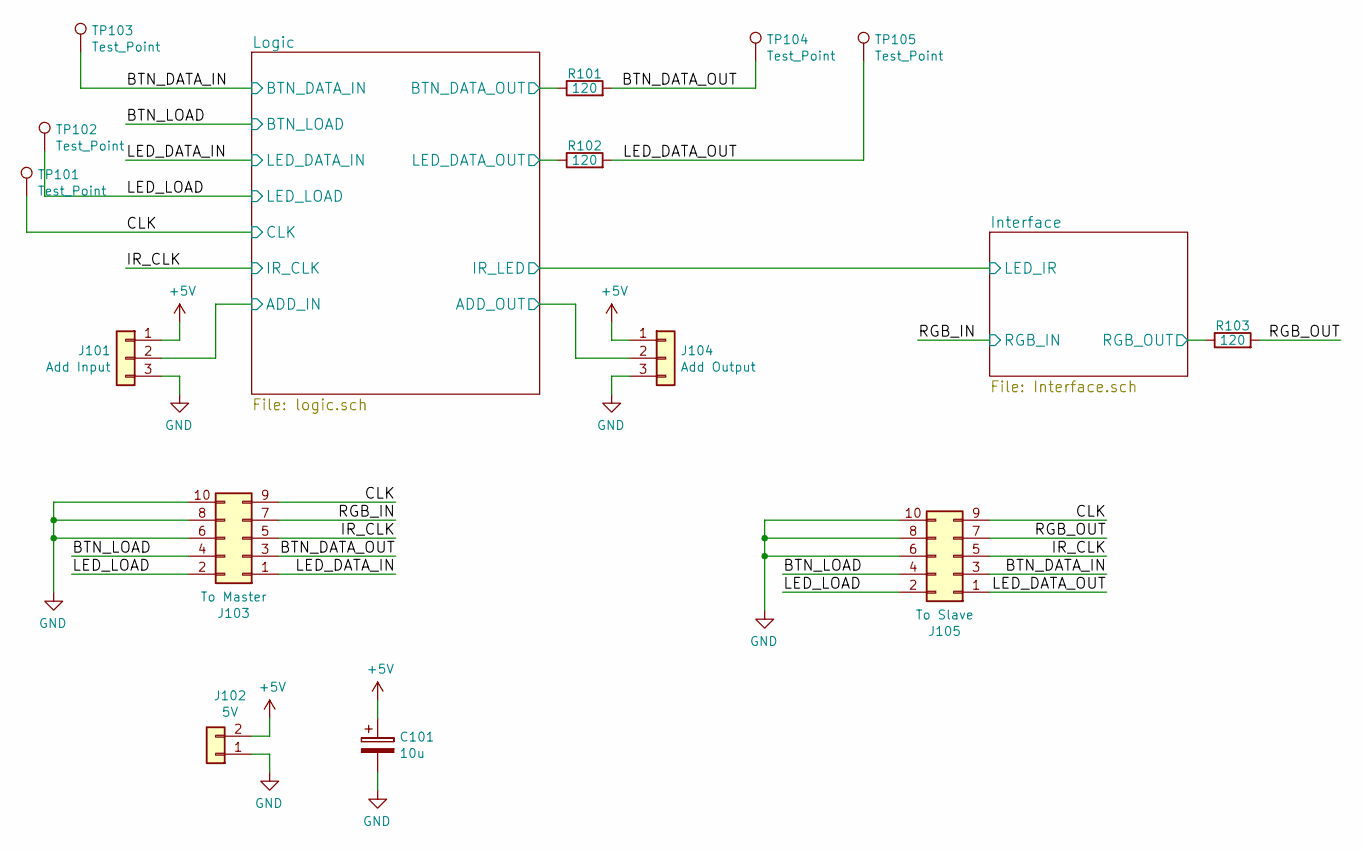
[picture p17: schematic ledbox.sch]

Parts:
C101: 10u; CP_Radial_D6.3mm_P2.50mm
J101: Add Input; Molex_KK-6410-03_03x2.54mm_Straight
J102: 5V; TerminalBlock_Phoenix_MKDS1.5-2pol
J103: To Master; IDC-Header_2x05_Pitch2.54mm_Straight
J104: Add Output; Molex_KK-6410-03_03x2.54mm_Straight
J105: To Slave; IDC-Header_2x05_Pitch2.54mm_Straight
R101, R102, R103: 120; R_0805
TP101, TP102, TP103, TP104, TP105: Test_Point; TestPoint_Pad_D1.0mm

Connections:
+5V: C101.1, J101.1, J102.2, J104.1; also elsewhere on the board
/BTN_DATA_IN: J105.3, TP103.1; also elsewhere on the board
/BTN_DATA_OUT: J103.3, R101.2, TP104.1
/BTN_LOAD: J103.4, J105.4; also elsewhere on the board
/CLK: J103.9, J105.9, TP101.1; also elsewhere on the board
/IR_CLK: J103.5, J105.5; also elsewhere on the board
/Interface/RGB_OUT: R103.1; also elsewhere on the board
/LED_DATA_IN: J103.1; also elsewhere on the board
/LED_DATA_OUT: J105.1, R102.2, TP105.1
/LED_LOAD: J103.2, J105.2, TP102.1; also elsewhere on the board
/Logic/ADD_IN: J101.2; also elsewhere on the board
/Logic/ADD_OUT: J104.2; also elsewhere on the board
/Logic/BTN_DATA_OUT: R101.1; also elsewhere on the board
/Logic/LED_DATA_OUT: R102.1; also elsewhere on the board
/RGB_IN: J103.7; also elsewhere on the board
/RGB_OUT: J105.7, R103.2
GND: C101.2, J101.3, J102.1, J103.6, J103.8, J103.10, J104.3, J105.6, J105.8, J105.10; also elsewhere on the board

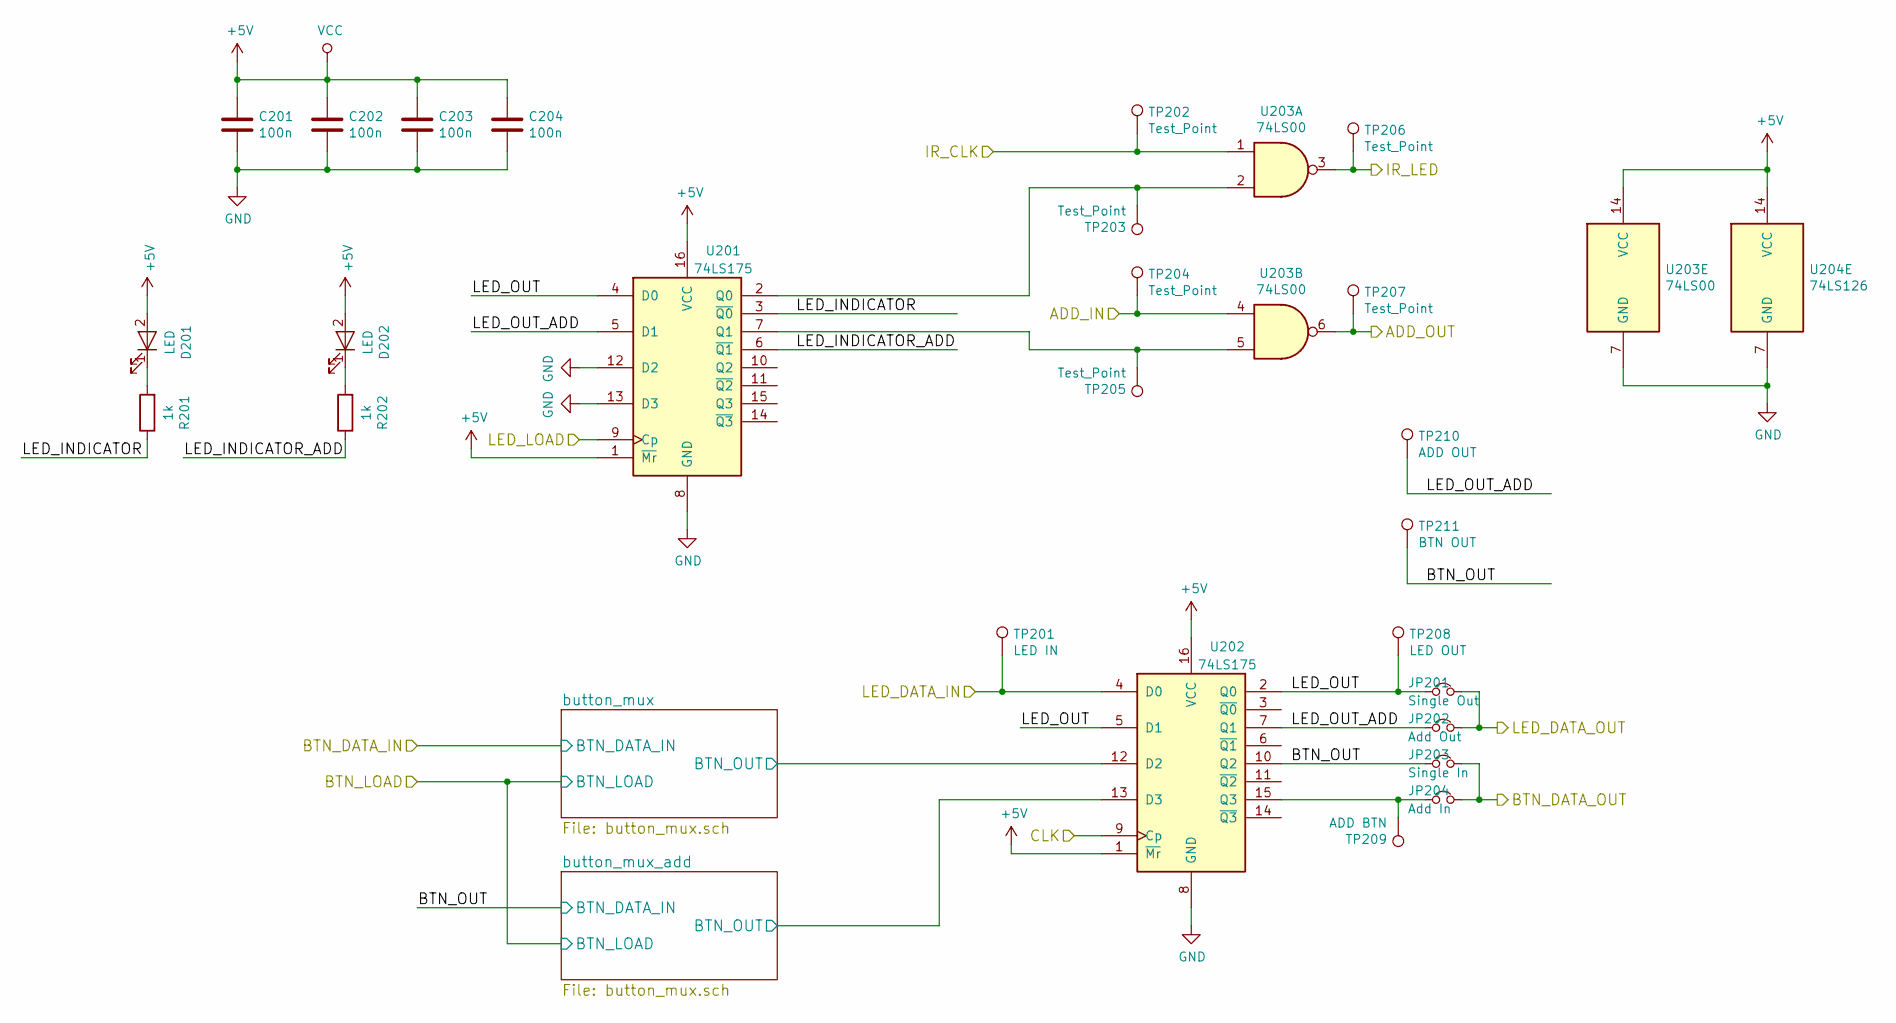
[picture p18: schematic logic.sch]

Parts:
C201, C202, C203, C204: 100n; C_0805
D201, D202: LED; LED_D3.0mm
JP201: Single Out; Jumper_SMD_02
JP202: Add Out; Jumper_SMD_02
JP203: Single In; Jumper_SMD_02
JP204: Add In; Jumper_SMD_02
R201, R202: 1k; R_0805
TP201: LED IN; TestPoint_Pad_D1.0mm
TP202, TP203, TP204, TP205, TP206, TP207: Test_Point; TestPoint_Pad_D1.0mm
TP208: LED OUT; TestPoint_Pad_D1.0mm
TP209: ADD BTN; TestPoint_Pad_D1.0mm
TP210: ADD OUT; TestPoint_Pad_D1.0mm
TP211: BTN OUT; TestPoint_Pad_D1.0mm
U201, U202: 74LS175; DIP-16_W7.62mm_LongPads
U203: 74LS00; DIP-14_W7.62mm_LongPads
U204: 74LS126; DIP-14_W7.62mm_LongPads

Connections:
+5V: C201.1, C202.1, C203.1, C204.1, D201.2 (A), D202.2 (A), U201.1 (~Mr), U201.16 (VCC), U202.1 (~Mr), U202.16 (VCC), U203.14 (VCC), U204.14 (VCC); also elsewhere on the board
/BTN_DATA_IN: U204.2; also elsewhere on the board
/BTN_LOAD: U203.9, U203.10, U204.4; also elsewhere on the board
/CLK: U202.9 (Cp); also elsewhere on the board
/IR_CLK: TP202.1, U203.1; also elsewhere on the board
/LED_DATA_IN: TP201.1, U202.4 (D0); also elsewhere on the board
/LED_LOAD: U201.9 (Cp); also elsewhere on the board
/Logic/ADD_IN: TP204.1, U203.4; also elsewhere on the board
/Logic/ADD_OUT: TP207.1, U203.6; also elsewhere on the board
/Logic/BTN_DATA_OUT: JP203.2, JP204.2; also elsewhere on the board
/Logic/BTN_OUT: JP203.1, TP211.1, U202.10 (Q2); also elsewhere on the board
/Logic/IR_LED: TP206.1, U203.3; also elsewhere on the board
/Logic/LED_DATA_OUT: JP201.2, JP202.2; also elsewhere on the board
/Logic/LED_INDICATOR: R201.1, U201.3 (~Q0)
/Logic/LED_INDICATOR_ADD: R202.1, U201.6 (~Q1)
/Logic/LED_OUT: JP201.1, TP208.1, U201.4 (D0), U202.2 (Q0), U202.5 (D1)
/Logic/LED_OUT_ADD: JP202.1, TP210.1, U201.5 (D1), U202.7 (Q1)
GND: C201.2, C202.2, C203.2, C204.2, U201.8 (GND), U201.12 (D2), U201.13 (D3), U202.8 (GND), U203.7 (GND), U204.7 (GND); also elsewhere on the board
unnamed: D201.1 (K), R201.2
unnamed: D202.1 (K), R202.2
unnamed: JP204.1, TP209.1, U202.15 (Q3)
unnamed: TP203.1, U201.2 (Q0), U203.2
unnamed: TP205.1, U201.7 (Q1), U203.5

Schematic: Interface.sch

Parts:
C501, C502, C503: 10u; C_0805
C504: 100n; C_0805
J501: IR LED; Molex_KK-6410-03_03x2.54mm_Straight
JP501: IR 12mA; Jumper_SMD_02
JP502: IR 36mA; Jumper_SMD_02
JP503: IR 76mA; Jumper_SMD_02
Q501: AO3415A; SOT-23
R501, R504: 100; R_0805
R502: 47k; R_0805
R503: 220; R_0805
R505: 47; R_0805
TP501: RGB1; TestPoint_Pad_D1.0mm
TP502: RGB2; TestPoint_Pad_D1.0mm
TP503: IR LED; TestPoint_Pad_D1.0mm
TP504: IR PWM; TestPoint_Pad_D1.0mm
TP505: RGB3; TestPoint_Pad_D1.0mm
U501, U502, U503: WS2812B; LED_WS2812B-PLCC4

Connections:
+5V: C501.1, C502.1, C503.1, C504.1, Q501.2, R502.2, U501.1 (VDD), U502.1 (VDD), U503.1 (VDD); also elsewhere on the board
/Interface/IR_LED_DRV: J501.1, J501.3, R503.2, R504.2, R505.2, TP503.1
/Interface/RGB_OUT: U503.2 (DOUT); also elsewhere on the board
/Logic/IR_LED: R501.2; also elsewhere on the board
/RGB_IN: TP501.1, U501.4 (DIN), U502.4 (DIN), U503.4 (DIN); also elsewhere on the board
GND: C501.2, C502.2, C503.2, C504.2, J501.2, U501.3 (GND), U502.3 (GND), U503.3 (GND); also elsewhere on the board
unnamed: JP501.1, R503.1
unnamed: JP501.2, JP502.2, JP503.2, Q501.3, TP504.1
unnamed: JP502.1, R504.1
unnamed: JP503.1, R505.1
unnamed: Q501.1, R501.1, R502.1
unnamed: TP502.1, U501.2 (DOUT)
unnamed: TP505.1, U502.2 (DOUT)

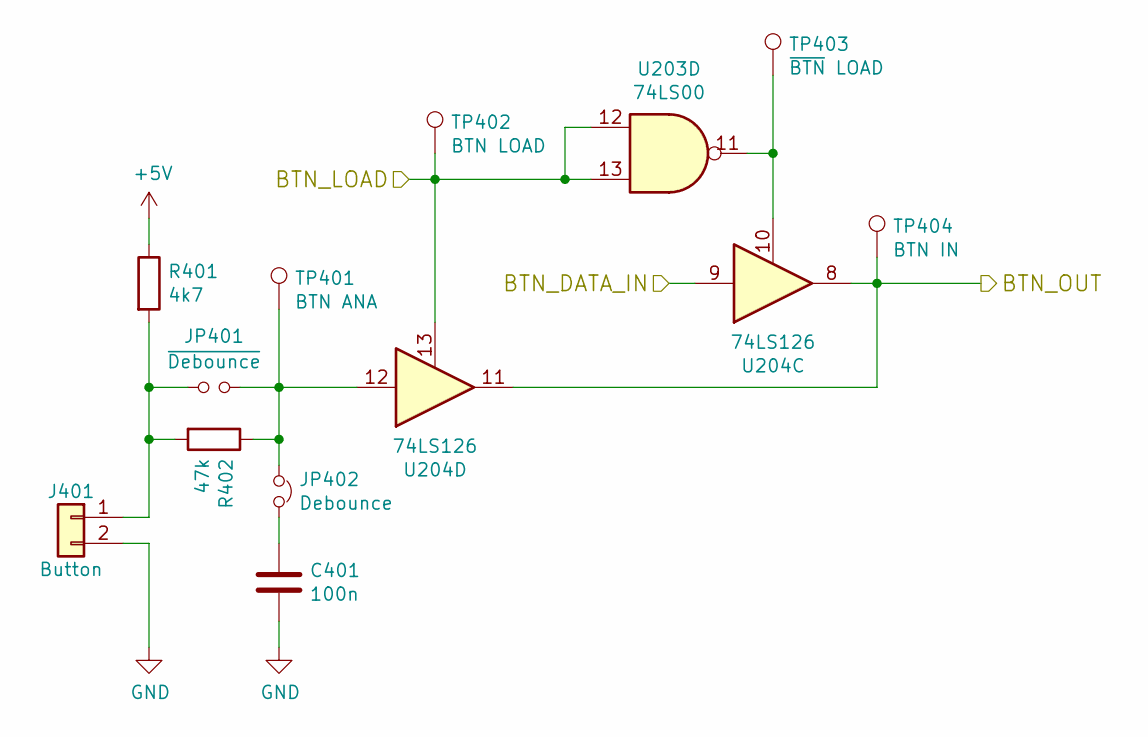
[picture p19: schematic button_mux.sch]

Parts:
C301: 100n; C_0805
J301: Button; Molex_KK-6410-02_02x2.54mm_Straight
JP301: ~Debounce; Jumper_SMD_02
JP302: Debounce; Jumper_SMD_02
R301: 4k7; R_0805
R302: 47k; R_0805
TP301: BTN ANA; TestPoint_Pad_D1.0mm
TP302: BTN LOAD; TestPoint_Pad_D1.0mm
TP303: ~BTN LOAD; TestPoint_Pad_D1.0mm
TP304: BTN IN; TestPoint_Pad_D1.0mm
U203: 74LS00; DIP-14_W7.62mm_LongPads
U204: 74LS126; DIP-14_W7.62mm_LongPads

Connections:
+5V: R301.1; also elsewhere on the board
/BTN_DATA_IN: U204.2; also elsewhere on the board
/BTN_LOAD: TP302.1, U203.9, U203.10, U203.12, U203.13, U204.4, U204.13; also elsewhere on the board
/Logic/BTN_OUT: U204.9; also elsewhere on the board
GND: C301.2, J301.2; also elsewhere on the board
unnamed: C301.1, JP302.2
unnamed: J301.1, JP301.1, R301.2, R302.2

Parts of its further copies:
C401: 100n; C_0805
J401: Button; Molex_KK-6410-02_02x2.54mm_Straight
JP401: ~Debounce; Jumper_SMD_02
JP402: Debounce; Jumper_SMD_02
R401: 4k7; R_0805
R402: 47k; R_0805
TP401: BTN ANA; TestPoint_Pad_D1.0mm
TP402: BTN LOAD; TestPoint_Pad_D1.0mm
TP403: ~BTN LOAD; TestPoint_Pad_D1.0mm
TP404: BTN IN; TestPoint_Pad_D1.0mm

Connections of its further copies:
+5V: R401.1; also elsewhere on the board
/BTN_LOAD: TP402.1; also elsewhere on the board
GND: C401.2, J401.2; also elsewhere on the board
unnamed: C401.1, JP402.2
unnamed: J401.1, JP401.1, R401.2, R402.2

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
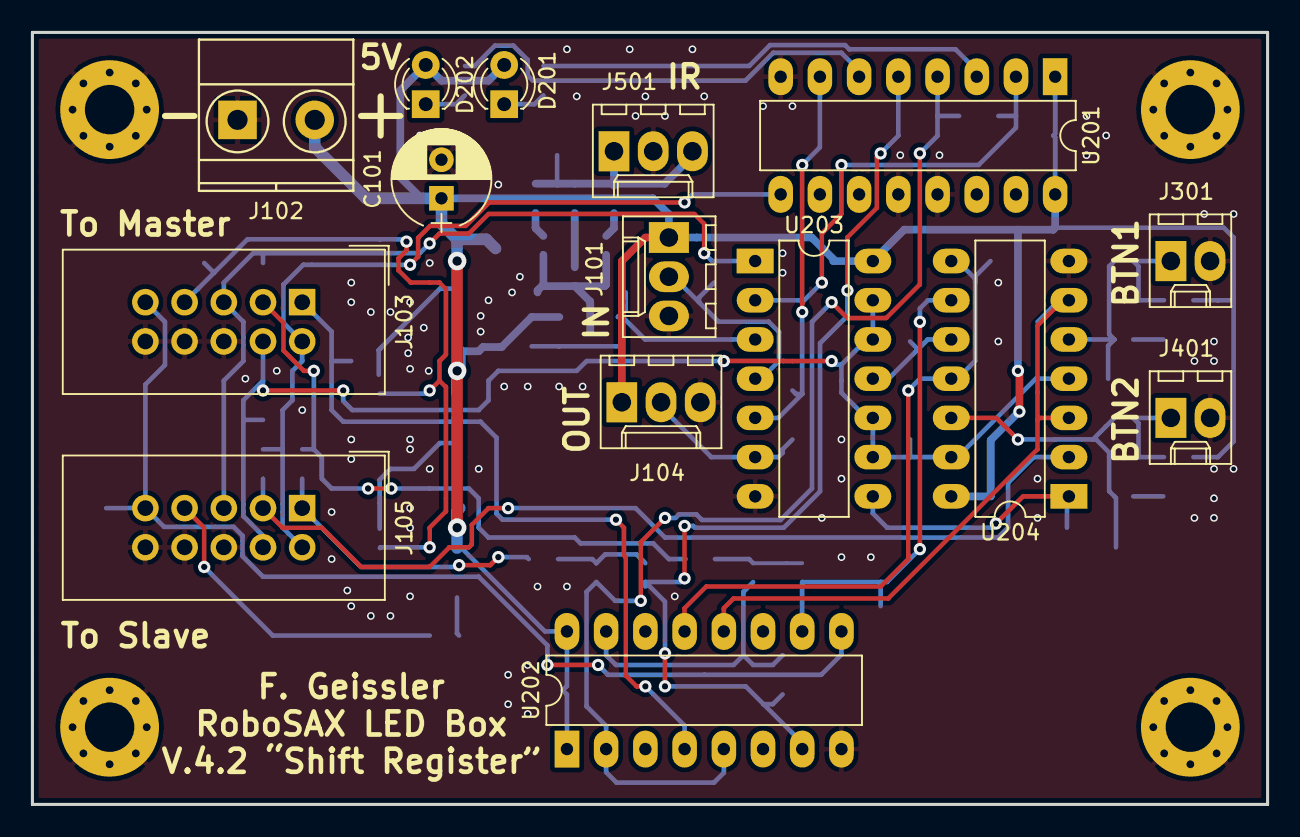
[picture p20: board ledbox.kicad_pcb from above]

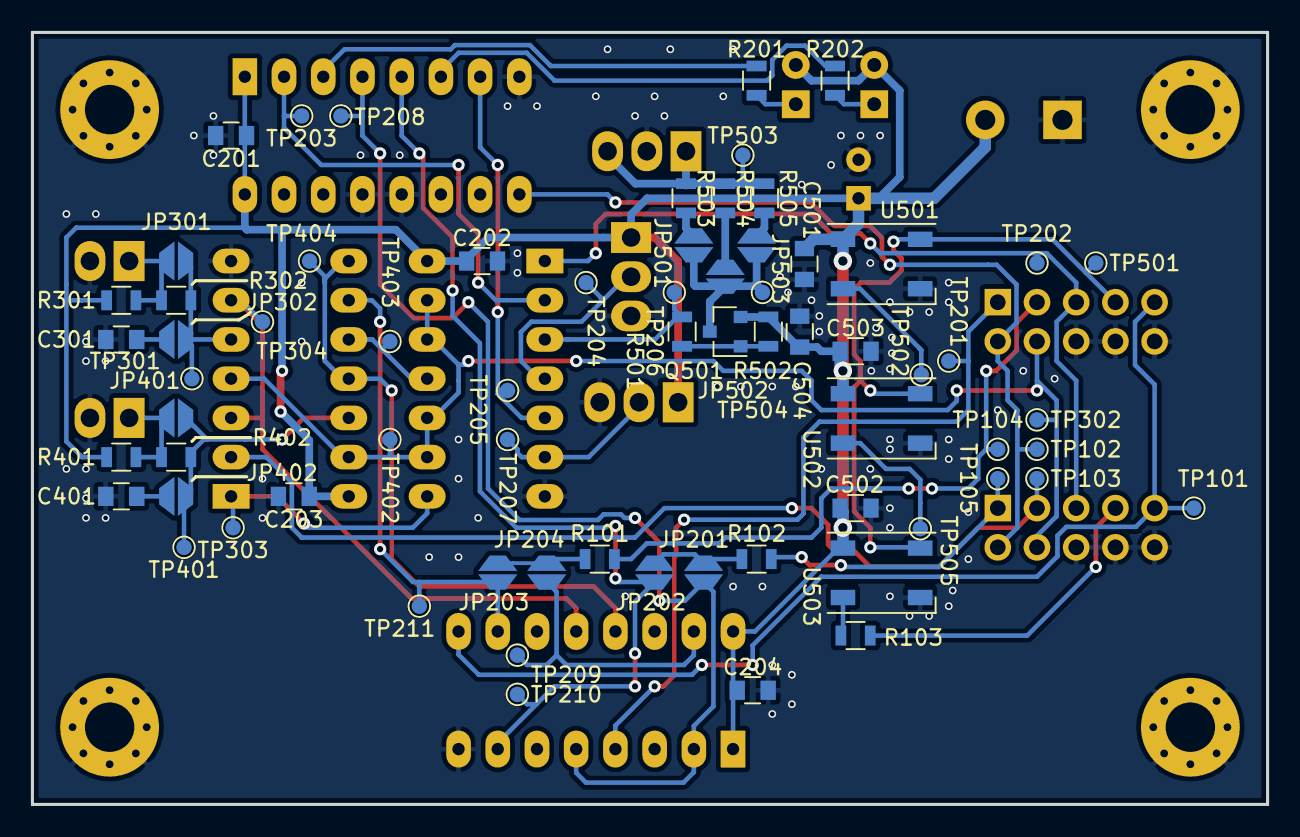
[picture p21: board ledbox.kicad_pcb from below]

Board: 2 copper layers, 80.0 x 50.0 mm, 83 parts (68 on the bottom side), 46 nets.

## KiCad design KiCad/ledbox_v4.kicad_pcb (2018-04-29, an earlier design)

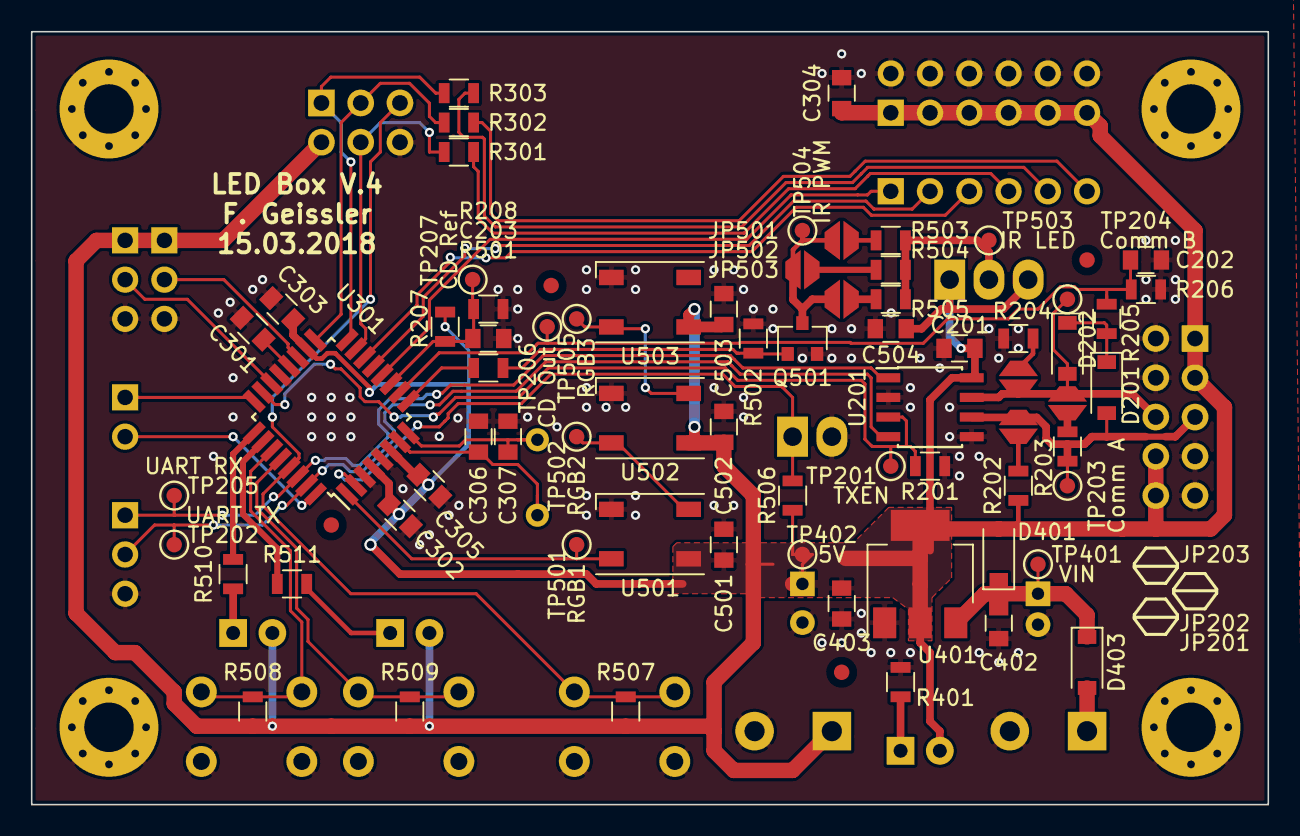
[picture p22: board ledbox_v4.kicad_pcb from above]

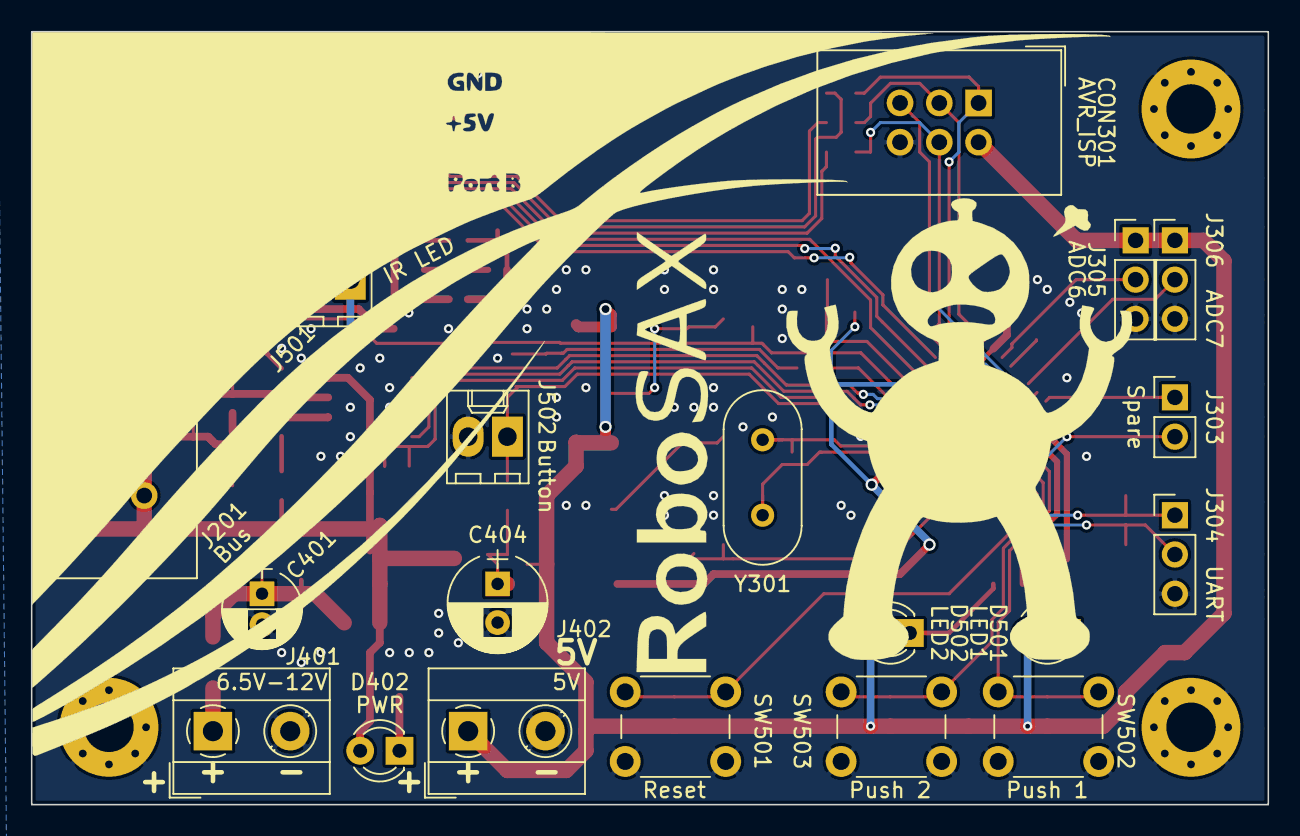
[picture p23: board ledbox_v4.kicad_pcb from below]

Board: 2 copper layers, 80.0 x 50.0 mm, 91 parts (21 on the bottom side), 50 nets.

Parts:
C201, C501, C502, C503: 10u; C_0805
C202, C306, C307: 22p; C_0805
C203: 470p; C_0805
C301, C302, C303, C304, C305, C402, C403, C504: 100n; C_0805
C401: 4u7; CP_Radial_D5.0mm_P2.00mm
C404: 47u; CP_Radial_D6.3mm_P2.50mm
CON301: AVR_ISP; IDC-Header_2x03_Pitch2.54mm_Straight
D201, D202, D401: 1N4148; D_SOD-123
D402: PWR; LED_D3.0mm
D403: PMEG4010ER; D_SOD-123
D501: LED1; LED_D3.0mm
D502: LED2; LED_D3.0mm
J201: Bus; IDC-Header_2x05_Pitch2.54mm_Straight
J301: Power B; Socket_Strip_Straight_2x06_Pitch2.54mm
J302: Port B; Socket_Strip_Straight_1x06_Pitch2.54mm
J303: Spare; Socket_Strip_Straight_1x02_Pitch2.54mm
J304: UART; Socket_Strip_Straight_1x03_Pitch2.54mm
J305: ADC6; Socket_Strip_Straight_1x03_Pitch2.54mm
J306: ADC7; Socket_Strip_Straight_1x03_Pitch2.54mm
J401: 6.5V-12V; TerminalBlock_MetzConnect_Type055_RT01502HDWU_Pitch5.00mm
J402: 5V; TerminalBlock_MetzConnect_Type055_RT01502HDWU_Pitch5.00mm
J501: IR LED; Molex_KK-6410-03_03x2.54mm_Straight
J502: Button; Molex_KK-6410-02_02x2.54mm_Straight
JP201: COMMA PU; Jumper_SMD_02
JP202: TERM; Jumper_SMD_02
JP203: COMMB PD; Jumper_SMD_02
JP501: IR 12mA; Jumper_SMD_02
JP502: IR 24mA; Jumper_SMD_02
JP503: IR 48mA; Jumper_SMD_02
Q501: NTR4003N; SOT-23
R201, R506, R507, R508, R509: 10k; R_0805
R202, R204, R301, R302, R303: 1k; R_0805
R203, R504: 150; R_0805
R205, R501: 100; R_0805
R206: 22k; R_0805
R207: 3k3; R_0805
R208, R401: 2k2; R_0805
R502: 100k; R_0805
R503: 300; R_0805
R505: 75; R_0805
R510, R511: 430; R_0805
SW501: Reset; SW_PUSH_6mm_h5mm
SW502: Push 1; SW_PUSH_6mm_h5mm
SW503: Push 2; SW_PUSH_6mm_h5mm
TP201: TXEN; TEST_10
TP202: UART TX; TEST_10
TP203: Comm A; TEST_10
TP204: Comm B; TEST_10
TP205: UART RX; TEST_10
TP206: CD Out; TEST_10
TP207: CD Ref; TEST_10
TP401: VIN; TEST_10
TP402: 5V; TEST_10
TP501: RGB1; TEST_10
TP502: RGB2; TEST_10
TP503: IR LED; TEST_10
TP504: IR PWM; TEST_10
TP505: RGB3; TEST_10
U201: ST485C; SOIC-8_3.9x4.9mm_Pitch1.27mm
U301: ATMEGA88A-AU; TQFP-32_7x7mm_Pitch0.8mm
U401: AZ1117-5.0; SOT-223-3_TabPin2
U501, U502: WS2812B; LED_WS2812B-PLCC4
U503: 3xWS2812B; LED_WS2812B-PLCC4
Y301: 20MHz; Crystal_HC49-U_Vertical

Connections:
+5V: C201.1, C302.1, C303.1, C304.1, C305.1, C403.1, C404.1, C501.1, C502.1, C503.1, C504.1, CON301.2, D401.2, D402.2, D501.2, D502.2, J201.1, J201.3, J201.8, J201.10, J301.1, J301.3, J301.5, J301.7, J301.9, J301.11, J305.1, J306.1, J402.1, J501.1, J501.3, R202.1, R207.1, R506.1, R507.1, R508.1, R509.1, TP402.1, U201.8, U301.4, U301.6, U301.18, U401.2, U501.1, U502.1, U503.1
+12V: C401.1, C402.1, D401.1, D403.1, TP401.1, U401.3
/Bus/AIN0: C202.1, R205.1, R206.1, TP206.1, U301.10
/Bus/AIN1: C203.1, R207.2, R208.1, TP207.1, U301.11
/Bus/COMM_A: D201.2, J201.5, JP201.2, R203.1, TP203.1, U201.6
/Bus/COMM_B: D202.2, J201.6, JP202.2, JP203.1, TP204.1, U201.7
/Bus/RX: J304.1, TP205.1, U201.1, U301.30
/Bus/TX: J304.2, TP202.1, U201.4, U301.31
/Bus/TX_EN: R201.2, TP201.1, U201.3, U301.23
/Controller/ADC6: J305.2, U301.19
/Controller/ADC7: J306.2, U301.22
/Controller/BTN: J502.1, R506.2, U301.2
/Controller/LED1: R510.2, U301.25
/Controller/LED2: R511.2, U301.26
/Controller/LED_IR: R501.2, U301.9
/Controller/MISO: CON301.1, R303.2, U301.16
/Controller/MOSI: CON301.4, R301.2, U301.15
/Controller/PB0: J302.1, U301.12
/Controller/PB1: J302.2, U301.13
/Controller/PB2: J302.3, U301.14
/Controller/PB3: J302.4, R301.1
/Controller/PB4: J302.5, R303.1
/Controller/PB5: J302.6, R302.1
/Controller/PC1: J303.1, U301.24
/Controller/PD2: J303.2, U301.32
/Controller/PUSH1: R508.2, SW502.1, U301.27
/Controller/PUSH2: R509.2, SW503.1, U301.28
/Controller/RGB_D: TP501.1, U301.1, U501.4
/Controller/SCK: CON301.3, R302.2, U301.17
/Controller/XTAL1: C306.1, U301.7, Y301.1
/Controller/XTAL2: C307.1, U301.8, Y301.2
/Controller/~RESET: CON301.5, R507.2, SW501.1, U301.29
/Interface/IR_LED_DRV: J501.2, R503.2, R504.2, R505.2, TP503.1
GND: C201.2, C202.2, C203.2, C301.1, C302.2, C303.2, C304.2, C305.2, C306.2, C307.2, C401.2, C402.2, C403.2, C404.2, C501.2, C502.2, C503.2, C504.2, CON301.6, J201.2, J201.4, J201.7, J201.9, J301.2, J301.4, J301.6, J301.8, J301.10, J301.12, J304.3, J305.3, J306.3, J401.2, J402.2, J502.2, Q501.2, R201.1, R204.2, R206.2, R208.2, R401.2, R502.1, SW501.2, SW502.2, SW503.2, U201.2, U201.5, U301.3, U301.5, U301.21, U401.1, U501.3, U502.3, U503.3
unnamed: C301.2, U301.20
unnamed: D201.1, D202.1, R205.2
unnamed: D402.1, R401.1
unnamed: D403.2, J401.1
unnamed: D501.1, R510.1
unnamed: D502.1, R511.1
unnamed: JP201.1, R202.2
unnamed: JP202.1, R203.2
unnamed: JP203.2, R204.1
unnamed: JP501.1, R503.1
unnamed: JP501.2, JP502.2, JP503.2, Q501.3, TP504.1
unnamed: JP502.1, R504.1
unnamed: JP503.1, R505.1
unnamed: Q501.1, R501.1, R502.2
unnamed: TP502.1, U501.2, U502.4
unnamed: TP505.1, U502.2, U503.4

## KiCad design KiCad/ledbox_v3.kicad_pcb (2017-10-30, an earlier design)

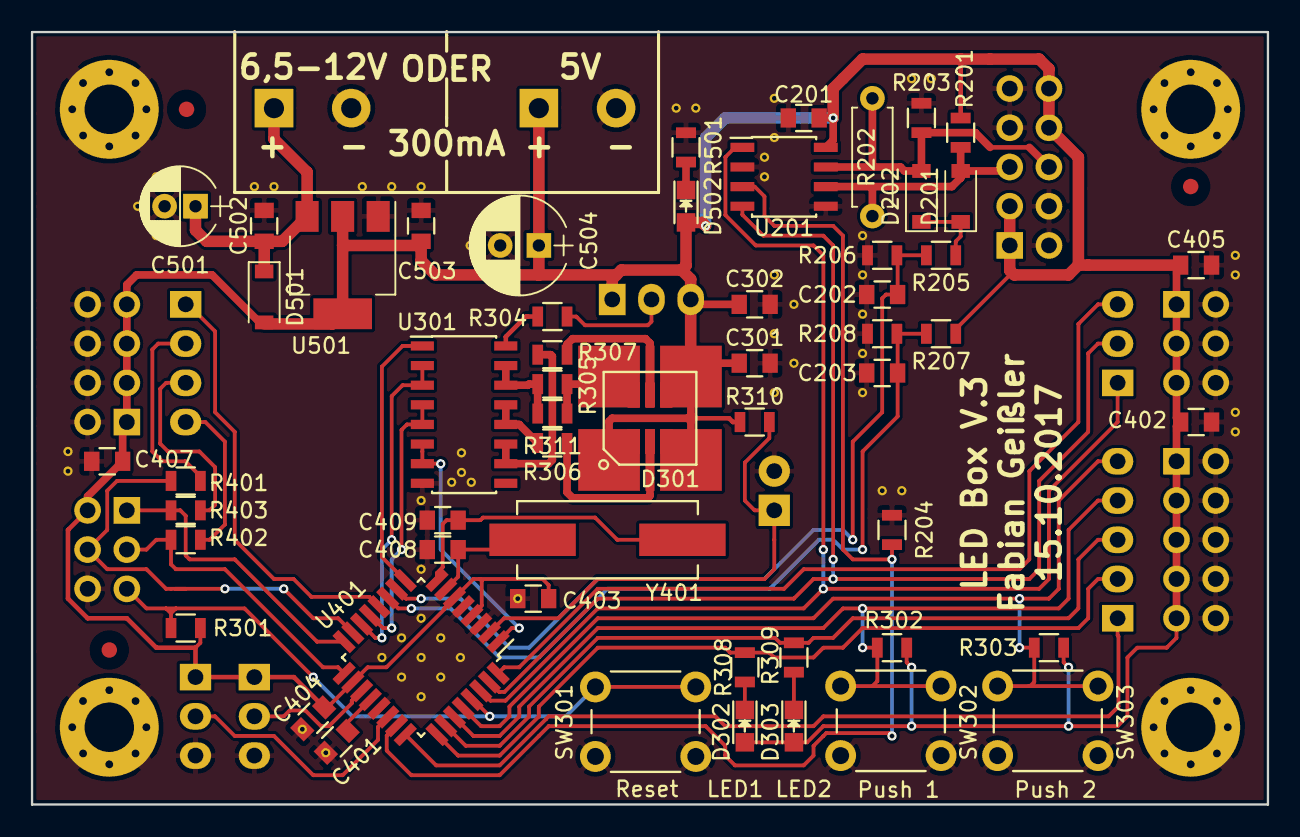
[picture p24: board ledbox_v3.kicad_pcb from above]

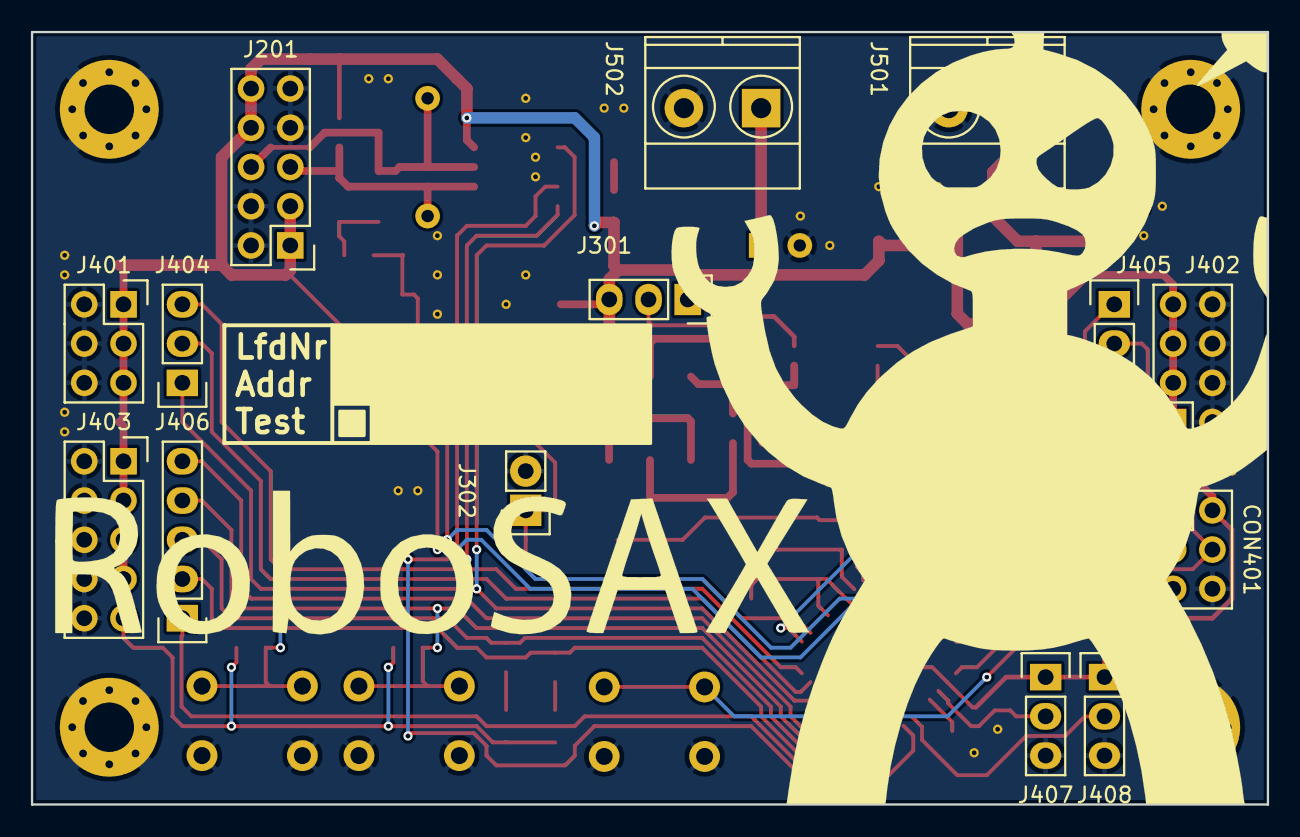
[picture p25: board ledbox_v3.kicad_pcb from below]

Board: 2 copper layers, 80.0 x 50.0 mm, 69 parts (14 on the bottom side), 46 nets.

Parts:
C201, C301: 10u; C_0805
C202: 22p; C_0805
C203: 470p; C_0805
C302, C401, C402, C403, C404, C405, C407, C502, C503: 100n; C_0805
C408, C409: DNP/22p; C_0805
C501: 4u7; CP_Radial_D5.0mm_P2.00mm
C504: 47u; CP_Radial_D6.3mm_P2.50mm
CON401: AVR_ISP; Pin_Header_Straight_2x03
D201, D202, D501: 1N4148; D_SOD-123
D301: LRTBG6TG; LED-6-BIG
D302: LED1; LED_0805
D303, D502: LED2; LED_0805
J201: Bus; Pin_Header_Straight_2x05
J301: IR LED; Pin_Header_Straight_1x03
J302: Button; Pin_Header_Straight_1x02
J401: Power; Socket_Strip_Straight_2x03
J402: Power; Socket_Strip_Straight_2x04
J403: Power; Socket_Strip_Straight_2x05
J404: Port D; Socket_Strip_Straight_1x03
J405: Port B; Socket_Strip_Straight_1x04
J406: Port C; Socket_Strip_Straight_1x05
J407: ADC6; Socket_Strip_Straight_1x03
J408: ADC7; Socket_Strip_Straight_1x03
J501: 6.5V-12V; TerminalBlock_Pheonix_MKDS1.5-2pol
J502: 5V; TerminalBlock_Pheonix_MKDS1.5-2pol
R201, R203: DNP/1k; R_0805
R202: DNP/150; R_Axial_DIN0207_L6.3mm_D2.5mm_P7.62mm_Horizontal
R204, R301, R302, R303, R310: 10k; R_0805
R205: 100; R_0805
R206: 22k; R_0805
R207: 3k3; R_0805
R208: 2k2; R_0805
R304: 150; R_0805
R305, R311: 82; R_0805
R306, R307: 22; R_0805
R308, R309, R501: 430; R_0805
R401, R402, R403: 1k; R_0805
SW301: Reset; SW_PUSH_6mm_h5mm
SW302: Push 1; SW_PUSH_6mm_h5mm
SW303: Push 2; SW_PUSH_6mm_h5mm
U201: ST485C; SOIC-8_3.9x4.9mm_Pitch1.27mm
U301: ULN2003; SOIC-16_3.9x9.9mm_Pitch1.27mm
U401: ATMEGA88-20AU; TQFP-32_7x7mm_Pitch0.8mm
U501: AZ1117-5.0; SOT-223-3Lead_TabPin2
Y401: DNP/20MHz; Crystal_HC49-SD_SMD

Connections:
+5V: C201.1, C301.1, C302.1, C402.1, C403.1, C404.1, C405.1, C407.1, C503.1, C504.1, CON401.2, D301.1, D301.3, D301.4, D302.2, D303.2, D501.2, D502.2, J201.1, J201.3, J201.8, J201.10, J301.1, J301.3, J401.1, J401.3, J401.5, J402.1, J402.3, J402.5, J402.7, J403.1, J403.3, J403.5, J403.7, J403.9, J407.1, J408.1, J502.1, R201.1, R207.1, R301.1, R302.1, R303.1, R310.1, U201.8, U401.4, U401.6, U401.18, U501.2
+12V: C501.1, C502.1, D501.1, J501.1, U501.3
/Bus/AIN0: C202.1, R205.1, R206.1, U401.10
/Bus/AIN1: C203.1, R207.2, R208.1, U401.11
/Bus/COMM_A: D201.2, J201.5, R201.2, R202.1, U201.6
/Bus/COMM_B: D202.2, J201.6, R202.2, R203.1, U201.7
/Bus/RX: J404.1, U201.1, U401.30
/Bus/TX: J404.2, U201.4, U401.31
/Bus/TX_EN: R204.2, U201.3, U401.23
/Controller/ADC6: J407.2, U401.19
/Controller/ADC7: J408.2, U401.22
/Controller/BTN: J302.1, R310.2, U401.2
/Controller/LED1: J406.2, R308.2, U401.25
/Controller/LED2: J406.3, R309.2, U401.26
/Controller/LED_IR: U301.1, U401.9
/Controller/MISO: CON401.1, R403.2, U401.16
/Controller/MOSI: CON401.4, R401.2, U401.15
/Controller/PB0: J405.1, U401.12
/Controller/PB3: J405.2, R401.1
/Controller/PB4: J405.3, R403.1
/Controller/PB5: J405.4, R402.1
/Controller/PC1: J406.1, U401.24
/Controller/PD2: J404.3, U401.32
/Controller/PUSH1: J406.4, R302.2, SW302.1, U401.27
/Controller/PUSH2: J406.5, R303.2, SW303.1, U401.28
/Controller/PWM_B: U301.6, U301.7, U401.1
/Controller/PWM_G: U301.4, U301.5, U401.13
/Controller/PWM_R: U301.2, U301.3, U401.14
/Controller/SCK: CON401.3, R402.2, U401.17
/Controller/XTAL1: C408.1, U401.7, Y401.1
/Controller/XTAL2: C409.1, U401.8, Y401.2
/Controller/~RESET: CON401.5, R301.2, SW301.1, U401.29
/Interface/IR_LED_DRV: J301.2, R304.1
GND: C201.2, C202.2, C203.2, C301.2, C302.2, C401.1, C402.2, C403.2, C404.2, C405.2, C407.2, C408.2, C409.2, C501.2, C502.2, C503.2, C504.2, CON401.6, J201.2, J201.4, J201.7, J201.9, J302.2, J401.2, J401.4, J401.6, J402.2, J402.4, J402.6, J402.8, J403.2, J403.4, J403.6, J403.8, J403.10, J407.3, J408.3, J501.2, J502.2, R203.2, R204.1, R206.2, R208.2, R501.2, SW301.2, SW302.2, SW303.2, U201.2, U201.5, U301.8, U401.3, U401.5, U401.21, U501.1
unnamed: C401.2, U401.20
unnamed: D201.1, D202.1, R205.2
unnamed: D301.2, R306.1
unnamed: D301.5, R307.1
unnamed: D301.6, R305.1, R311.1
unnamed: D302.1, R308.1
unnamed: D303.1, R309.1
unnamed: D502.1, R501.1
unnamed: R304.2, U301.16
unnamed: R305.2, R311.2, U301.14, U301.15
unnamed: R306.2, U301.12, U301.13
unnamed: R307.2, U301.10, U301.11

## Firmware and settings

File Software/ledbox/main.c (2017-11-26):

/*
 * main.c
 *
 *  Created on: 22.10.2017
 *      Author: fabiangeissler
 */

#include "avr/io.h"
#include "avr/interrupt.h"
#include "avr/pgmspace.h"
#include "util/delay.h"

#include "periphery/pwm.h"
#include "periphery/pwm_hybrid.h"
#include "settings.h"
#include "periphery/systick.h"
#include "software/brightness.h"
#include "board/rgbled.h"
#include "board/push.h"
#include "board/led.h"
#include "bus/csma.h"

#define PUSH_DEBOUNCE	50

int main()
{
	// Set OCR1A:B and OCR2B pin to output
	DDRB |= (1 << PB1) | (1 << PB2);
	DDRD |= (1 << PD3);

	// Enable global interrupts
	sei();

	// init RGB LED
	rgb_init();
	//rgb_setcolor(COLOR_WHITE);

	systick_init();

	//uart_init();
	csma_init();

	// Init on board buttons and leds
	push_init();
	led_init();

	led_set(LED_SET | LED1);
	led_set(LED_RESET | LED2);

	uint8_t val = 0;
	uint32_t time = systick_getticks();
	uint32_t fade_time = time;
	uint32_t debounce_time = time;
	uint32_t corr[3] =  {0x8000, 0x8000, 0x8000};
	int32_t del = 0x0000;
	uint8_t mode = 0;

	while(1)
	{
		time = systick_getticks();

		csma_loop(time);

		if((time - fade_time) >= SYSTICK_TICKS_MS(50))
		{
//			fade_time = time;
//
//			//uart_puts("Das ist ein sehr langer test string!!");
//			rgb_setcolor(color_fromhsv(val, 255, 255));
//
//			++val;
		}

		if((time - debounce_time) >= SYSTICK_TICKS_MS(PUSH_DEBOUNCE))
		{
			debounce_time = time;

			int8_t push1, push2;

			push_check(&push1, &push2);

			switch(push1)
			{
			case 1: // button pushed
				del = 0x100;
				break;
			case -1: // button released
				del = 0;
				break;
			}

			switch(push2)
			{
			case 1: // button pushed
				del = -0x100;
				break;
			case -1: // button released
				del = 0;
				break;
			}

			if((push1 == 1) && (push1 == push2))
			{
				++mode;

				switch(mode)
				{
				case 1:
					rgb_setcolor(COLOR_GREEN);
					break;
				case 2:
					rgb_setcolor(COLOR_BLUE);
					break;
				case 0:
				default:
					rgb_setcolor(COLOR_RED);
					mode = 0;
				}

				_delay_ms(500);
				rgb_setcolor(COLOR_WHITE);
			}

			corr[mode] += del;

			if(del != 0)
			{
				rgb_setwhitecorrection(corr[0], corr[1], corr[2]);
				rgb_setcolor(COLOR_WHITE);
			}
		}
	}
}

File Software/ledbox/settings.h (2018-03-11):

/*
 * settings.h
 *
 *  Created on: 23.10.2017
 *      Author: fabiangeissler
 */

#ifndef SETTINGS_H_
#define SETTINGS_H_

#include "stdint.h"
#include "periphery/systick.h"

// In uncommented the following switch will prevent the SETTINGS_BUS_CSTICKS assert error
// by setting the define to a fixed constant of 1. Do not use if the assertion does not
// fail.
#define SETTINGS_BUS_CSTICKS_ASSERT_ERROR_SWITCH

// The following switch enables RGB LED brightness linearization if uncommented.
//#define SETTINGS_BRIGHTNESS_LINEARIZATION

// Global RGB LED bit setting.
#define SETTINGS_PWM_BIT_COUNT		14
#define SETTINGS_PWM_TOP				(uint16_t)(~(0xFFFF << SETTINGS_PWM_BIT_COUNT))

// IR LED Frequency in Hz
#define SETTINGS_IR_FREQUENCY		38000
// IR LED baud rate
#define SETTINGS_IR_BAUD				400
// IR LED data buffer size in byte
#define SETTINGS_IR_BSIZE			10

// Global bus UART interface baud rate setting.
#define SETTINGS_BUS_BAUD			9600
// Maximum size of the packet including header
#define SETTINGS_BUS_PACKETSIZEMAX	128

// Collision avoidance steps.
#define SETTINGS_BUS_CASTEPS 		50
// User priority Steps.
#define SETTINGS_BUS_USERPRIOSTEPS	5

// Bus delays in milliseconds.
// Collision avoidance period step time (uses IR timer)
#define SETTINGS_BUS_CASTEPTIME		(1.0 / (float)SETTINGS_IR_FREQUENCY)
// Delay before starting a transmission.
#define SETTINGS_BUS_TXDELAY			5
// Delay before listening.
#define SETTINGS_BUS_RXDELAY			2
// Timeout for single byte transmission.
#define SETTINGS_BUS_BYTETIMEOUT		10
// Timeout for single byte transmission.
#define SETTINGS_BUS_ERRORDELAY		1

#endif /* SETTINGS_H_ */

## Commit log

2017-10-05 Erste Version des LED Box Prototypen
    [ledbox.kicad_pcb, ledbox.sch]
2017-10-05 LED Vorwiderstände auf E-Reihen angepasst
    [ledbox.sch]
2017-10-05 Ordner plot in output geändert. BOM hinzugefügt
    [ledbox.sch]
2017-10-05 Version 1.1: - RGB LED Symbol angepasst - Button und IR LED auf eine vierer Klemmleiste Footprints assoziiert
    [ledbox.sch]
2017-10-06 Version 2 - Anforderungen für Software hinzugefügt - CSMA/CA anstatt CSMA/CD - Kollisionsdetektion hinzugefügt - Verbinder für IR LED und Button getrennt und unterschiedlich gemacht - zusätzlich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
    [ledbox.sch]
2017-10-06 Software und Buszugriff PDFs getrennt
2017-10-06 LTSpice asc der Bus Kollisionserkennung hinzugefügt
2017-10-07 Exchanged SN75176B with ST485C
    [ledbox.sch]
2017-10-09 Version 3: - ATmega88 - Schaltplan auf verschiedene sheets aufgeteilt - div. kleine Änderungen
    [Bus.sch, Controller.sch, Interface.sch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]
2017-10-15 Board Layout (SMD) fertiggestellt
    [Bus.sch, Controller.sch, Interface.sch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]
2017-10-15 Kleine Verbesserungen
    [ledbox.kicad_pcb]
2017-10-15 Gerber Dateien erstellt
    [ledbox-B.Cu.gbl, ledbox-B.Mask.gbs, ledbox-B.SilkS.gbo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]
2017-10-16 Kleine Veränderungen
    [Bus.sch, Controller.sch, Interface.sch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]
2017-10-16 Befestigungsbohrungen in Top Paste Layer aufgenommen -> Stencil kann eingespannt werden
    [ledbox.kicad_pcb]
2017-10-16 Gerber Dateinamen angepasst
    [ledbox.gbl, ledbox.gbo, ledbox.gbs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]
2017-10-16 Atmega88 gegen Atmega88A getauscht
    [Bus.sch, Controller.sch, Interface.sch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]
2017-10-22 Ordnerstruktur geändert
    [Bus.sch, Controller.sch, Interface.sch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]
2017-10-23 Systick added, different PWM resolution extender tested.
2017-10-30 Fitted software to prototype boards
2017-11-21 Started CSMA and BUS development. Added Board peripherals.
    [Bus.sch, Controller.sch, Interface.sch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]
2017-11-25 Replaced uart module with more specialized rs485 module for USART peripheral control.
    [csma.c, main.c, rs485.c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]
2017-11-26 IR LED modules added
2017-12-18 CSMA/CA changed to use IR timer
2018-03-11 Schematic Version 4 Some Software Changes
    [Bus.sch, Controller.sch, Interface.sch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]
2018-03-11 Changes to V4 Schematic, new Board design
    [Bus.sch, Controller.sch, Interface.sch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]
2018-03-11 Added board plot
    [ledbox.kicad_pcb]
2018-03-15 Finished v4 board
    [Interface.sch, ledbox.kicad_pcb]
2018-03-15 Added version label
    [ledbox.kicad_pcb]
2018-04-29 Version 4 Shift Register
    [Controller.sch, Interface_v4.sch, button_mux.sch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]
2018-05-15 Regenerated schematic plot
2018-05-17 Applied changes for final design, placed test points.
    [Interface.sch, button_mux.sch, ledbox.kicad_pcb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]
2018-05-17 assigned transistor model
    [Interface.sch]
2018-05-17 paralleled RGB leds
    [Interface.sch, ledbox.kicad_pcb]
2018-05-17 Created final gerber files
    [ledbox.gbl, ledbox.gbo, ledbox.gbs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]
2018-05-17 turned data connectors to match cable layout
    [ledbox.kicad_pcb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]
2018-05-25 paste layer export
    [ledbox-B.Paste.dxf]
2018-05-29 added board plots
    [ledbox.kicad_pcb]
2018-05-30 added solder manual and test software
2018-05-30 added pin definitions to test software
